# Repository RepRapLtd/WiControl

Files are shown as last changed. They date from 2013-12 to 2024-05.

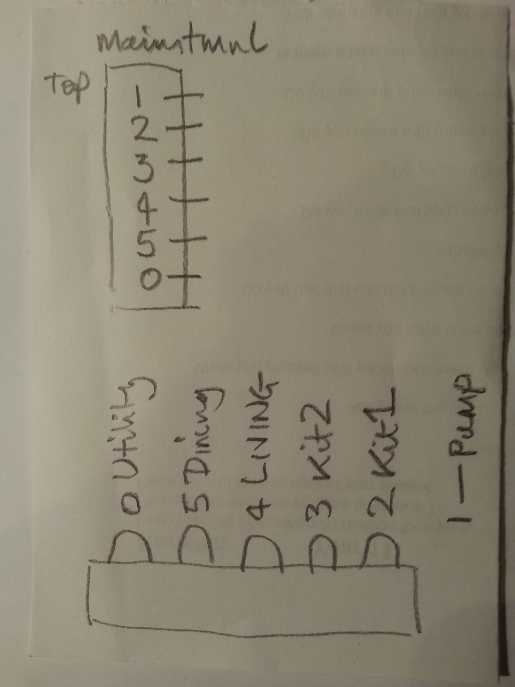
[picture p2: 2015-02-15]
PanStamp/Electronics/uf-connections.jpg

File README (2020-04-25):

Wireless Home/Building Control System
=====================================

Adrian Bowyer
RepRap Ltd
https://reprapltd.com

Licence: GPL

This is a system for controlling devices in buildings (primarily, but not exclusively, heating; it will also do lighting and other things) with a web interface.  It is fully open-source and free.  The licence is the GPL.

There are two versions:

  1. Raspberry Pi + PanStamp in the directory PanStamp. This has been working for a few years, and is now frozen and will not be developed further.

  2. WiFi based on the ESP-8266 in the directory ESP-8266.  This is in development.

Both start with a php script that serves web pages where you can edit, for example, temperature profiles for individual rooms.  That data is saved in files on the server.

The ESP-8266s (or Pi) then get that data and decide(s) what to turn on and off.

More documentation needs to be written...

More importantly, security is minimal and needs to be properly implemented.

See also (for homemade solenoid valves): https://www.thingiverse.com/thing:3496770

WiControl - ESP-8266
====================

This version does everything that the PanStamp version did, but more simply and robustly (the robustness has nothing to do with the hardware change; the PanStamps are fine; it has to do with a simplification of the protocols and hardware).

This version of the system will also support Google Home and Amazon Echo/Alexa.

Some more instructions here would be a good idea...

WiControl - Raspberry Pi + PanStamp
===================================

This allows temperature profiles to be set for each individual room for all times of the day and every day of the week.

It can be controlled using a web browser from anywhere.

It uses Panstamps (http://www.panstamp.com/) for the individual rooms and a Raspberry Pi (https://www.raspberrypi.org/) as the main building controller.

This repository contains all the software and all the hardware designs.

One thing it lacks is full documentation, as I created it for my own use and I know how it works.  Sorry.

Installation:
-------------

On the Pi:

This assumes you have an out-of-the-box Raspberry Pi SD card with no extra software installed.

First set your local timezone:

$ sudo dpkg-reconfigure tzdata

You may want to change the default name of the Pi ("raspberrypi") to something more appropriate 
like "heatingcontrol".  To do that:

$ sudo nano /etc/hostname

That file contains a single name - the name of the Pi.  Change it to what you want, save the file, then reboot.

Change you password:

$ passwd

And enable ssh:

$ sudo raspi-config

Next install Apache and PHP:

$ sudo apt-get update
$ sudo apt-get install apache2 -y
$ sudo apt-get install php5 libapache2-mod-php5 -y

At this point it is a good idea to check that the webserver is now running.  In the URL address bar of a web browser on a PC or phone type

  myname.home/

where myname is the Pi's name that you created above (some networks need myname.local instead).  If you don't get anything type 

$ ifconfig

on the Pi.  This will tell you the Pi's IP address (something like 192.168.1.163).  Type that IP address into the web browser's URL bar.  You should see the default Apache/Debian server homepage.

Next install ftp:

$ sudo apt-get install ftp

And the ftp demon:

$ sudo apt-get install pure-ftpd

Create an ftp user (see https://www.raspberrypi.org/documentation/remote-access/ftp.md) called "upload" with access to the html directory:

$ sudo groupadd ftpgroup
$ sudo useradd ftpuser -g ftpgroup -s /sbin/nologin -d /dev/null
$ pushd /var/www/html/
$ sudo chown -R ftpuser:ftpgroup .
$ sudo pure-pw useradd upload -u ftpuser -g ftpgroup -d /var/www/html -m
[** You will be asked to create a password for the user upload at this point**]
$ sudo pure-pw mkdb
$ sudo ln -s /etc/pure-ftpd/conf/PureDB /etc/pure-ftpd/auth/60puredb
$ sudo service pure-ftpd restart
$ popd

You next need to install the heating software:

$ git clone https://github.com/RepRapLtd/WiControl.git
$ cd WiControl/PanStamp

Copy the control file:

$ cp run-heat-control.sample run-heat-control

and edit the file run-heat-control and replace the "zone-1"s with the name of the zone you want.

Copy the sending file:

$ cp sendtemps.sample sendtemps

and edit the sendtemps file to include the ftp password you set above and to change zone-1 to the name of your zone.

Backup the webserver's index file, and copy all the heating web files there and set permissions:

$ sudo mv /var/www/html/index.html /var/www/html/index.html.old
$ cd Web
$ sudo cp -r * /var/www/html
$ sudo chown -R ftpuser:ftpgroup /var/www/html
$ sudo chmod 666 /var/www/html/*.dat
$ sudo chmod 777 /var/www/html/zone-1-Profiles

Finally

$ sudo crontab -e

and add a line at the end like this:

* * * * * /home/pi/WiControl/run-heat-control

That will cause the shell script run-heat-control to be run once a minute.

On the PanStamps:

You can just about run the Arduino IDE on the Raspberry Pi, but it's probably better to
use a big serious computer to do this bit.  Install the Arduino IDE on your computer if
you haven't already got it:

https://www.arduino.cc/en/Main/Software

And clone the repository https://github.com/RepRapLtd/WiControl.git as you did on the Pi.

Load the arduino program in the folder Panstamp-control into the IDE.

At the head of the file Control.h set up your heating zones and device names and numbers.  Load 
this program into each device (e.g. boiler, radiator) on your heating system.

Running
-------

When it runs it creates a status file called Status.

$ cat Status

will tell you what your system last did.  If you

$ touch Log

then each time run-heat-control runs it will append the status
report to the end of itself, which keeps a history and is therefore
useful for debugging.

When you have finished debugging don't forget to

$ rm Log

otherwise it will eventually fill up the SD/disc...

Adrian Bowyer

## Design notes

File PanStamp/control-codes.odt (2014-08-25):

Panstamp Heating etc control control codes

C0

Sleep or reset? Not yet implemented.

C1 Pn Hv [Ds]

Set output n to v. n = 0 is the MOSFET. Outputs 1 to 5 are on the 7 pin header, which goes:

+12v

Gnd

1 (Arduino D8)

2 (Arduino D9) - Not available in LED control mode

3 (Arduino A3 = D17)

4 (Arduino A1 = D15)

5 (Arduino A2 = D16)

The action happens after d seconds (default 0s).

C2

Return my temperature. When wireless requested this gives an integer in 0.1 degrees Celsius. From the serial interface it just gives degrees Celsius.

C3 An Ssome command

Send "some command" to device n

C4

Print/send firmware version number and my address.

C5 Pn Hv

Low level set Arduino pin n to value v. NB this also sets pin n to output mode.

C6 r0.7 g0.2 b0.1

Sets the LEDs to the rgb values specified in the range [0, 1].

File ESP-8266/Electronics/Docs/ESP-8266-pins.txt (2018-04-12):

esp8266_peri.h:#define GPC0   ESP8266_REG(0x328) //GPIO_PIN0 D3 (mini)
esp8266_peri.h:#define GPC1   ESP8266_REG(0x32C) //GPIO_PIN1 TX (mini)
esp8266_peri.h:#define GPC2   ESP8266_REG(0x330) //GPIO_PIN2 D4 (mini)
esp8266_peri.h:#define GPC3   ESP8266_REG(0x334) //GPIO_PIN3 RX (mini)
esp8266_peri.h:#define GPC4   ESP8266_REG(0x338) //GPIO_PIN4 D2 (mini)
esp8266_peri.h:#define GPC5   ESP8266_REG(0x33C) //GPIO_PIN5 D1 (mini)
esp8266_peri.h:#define GPC6   ESP8266_REG(0x340) //GPIO_PIN6 -
esp8266_peri.h:#define GPC7   ESP8266_REG(0x344) //GPIO_PIN7 
esp8266_peri.h:#define GPC8   ESP8266_REG(0x348) //GPIO_PIN8
esp8266_peri.h:#define GPC9   ESP8266_REG(0x34C) //GPIO_PIN9
esp8266_peri.h:#define GPC10  ESP8266_REG(0x350) //GPIO_PIN10
esp8266_peri.h:#define GPC11  ESP8266_REG(0x354) //GPIO_PIN11
esp8266_peri.h:#define GPC12  ESP8266_REG(0x358) //GPIO_PIN12 D6 (mini)
esp8266_peri.h:#define GPC13  ESP8266_REG(0x35C) //GPIO_PIN13 D7 (mini)
esp8266_peri.h:#define GPC14  ESP8266_REG(0x360) //GPIO_PIN14 D5 (mini)
esp8266_peri.h:#define GPC15  ESP8266_REG(0x364) //GPIO_PIN15 D8 (mini)
                                                 //GPIO_PIN16 D0 (mini)
LED_BUILTIN

d1-mini:

#define LED_BUILTIN 2

static const uint8_t D0   = 16;
static const uint8_t D1   = 5;
static const uint8_t D2   = 4;
static const uint8_t D3   = 0;
static const uint8_t D4   = 2;
static const uint8_t D5   = 14;
static const uint8_t D6   = 12;
static const uint8_t D7   = 13;
static const uint8_t D8   = 15;
static const uint8_t RX   = 3;
static const uint8_t TX   = 1;

d1:

#define LED_BUILTIN 2 //new ESP-12E GPIO2

static const uint8_t D0   = 3;
static const uint8_t D1   = 1;
static const uint8_t D2   = 16;
static const uint8_t D3   = 5;
static const uint8_t D4   = 4;
static const uint8_t D5   = 14;
static const uint8_t D6   = 12;
static const uint8_t D7   = 13;
static const uint8_t D8   = 0;
static const uint8_t D9   = 2;
static const uint8_t D10  = 15;
static const uint8_t D11  = 13;
static const uint8_t D12  = 12;
static const uint8_t D13  = 14;
static const uint8_t D14  = 4;
static const uint8_t D15  = 5;

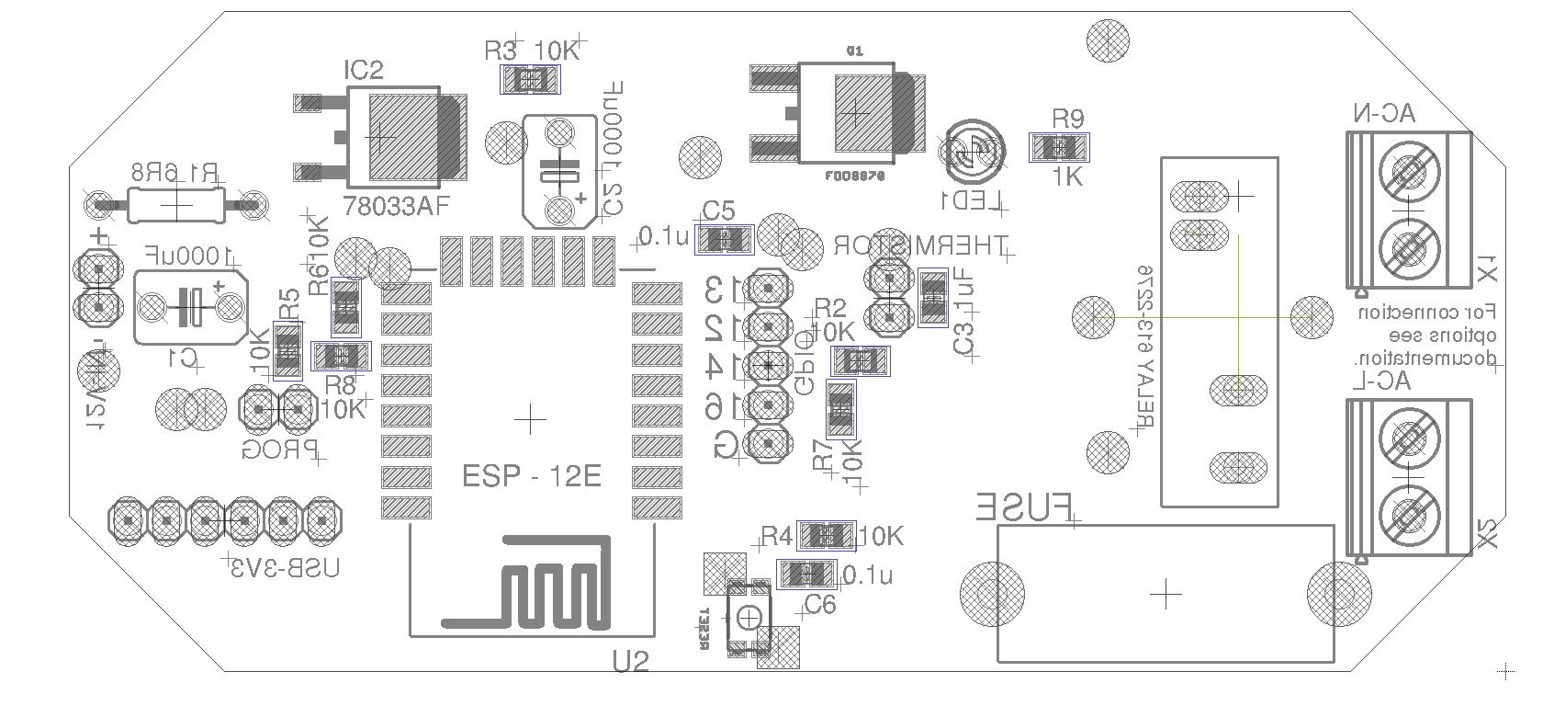
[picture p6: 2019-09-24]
ESP-8266/Electronics/PCB-under.png

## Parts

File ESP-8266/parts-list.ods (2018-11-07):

 | Part | Value | Totals | Supplier | Supplier part # | Our Part No | Item Description | Qty in stock | Qty to Order | Ordered
23 | ← Number of units
Electronics
 | 2 pin head |  | 3 |  |  |  | PCB pin header – 2 pin | 300 | -231
 | 5 pin head |  | 1 |  |  |  | PCB pin header – 5 pin | 70 | -47
 | 6 pin head |  | 1 |  |  |  | PCB pin header – 6 pin | 70 | -47
 | C2 | 1000uF | 2 | RS | 711-0980 |  | Electrolytic capacitor | 11 | 35 | 50
 | C3 | 1uF | 1 | RS | 698-3409 |  | 805 SMT capacitor | 16 | 7 | 10
 | C6 | 0.1u | 2 | Farnell | 2852354 |  | 805 SMT capacitor | 28 | 18
 | IC2 | 78033AF | 1 | RS | 751-5192 |  | 3.3V SMT regulator | 46 | -23
 | LED1 (red) | 3mm red LED | 1 | RS | 127-8385 |  | red LED | 45 | -22
 | Flying LED (grn) | 3mm green LED | 1 | RS | 247-1375 |  | green LED | 70 | -47
 | Q1 | FDD8870 | 1 | RS | 809-0950 |  | SMT power MOSFET | 6 | 17 | 20
 | R9 | 1K | 1 | RS | 901-3682 |  | 805 SMT resistor | 91 | -68
 | (R10) | 220R | 1 | RS | 683-2783 |  | 0.125W axial-lead resistor | 17 | 6 | 25
 | RESET | membrane button | 1 | Amazon/Ebay |  |  | push switch | 25 | -2
 | U$1 | FUSE | 0 | RS | 176-9047 |  | PCB fuse holder | 3 | -3
 | U$2 | relay | 0 | RS | 613-2276 |  | PCB 12v/240v relay | 2 | -2
 | U2 | ESP12E | 1 | Amazon/Ebay |  |  | SMT wireless module | 0 | 23
 | X2 | AC-L | 1 | RS | 144-4330 |  | 2-pin PCB screw terminal 5mm pitch | 14 | 9 | 10
 | Power supply |  | 1 | EBay |  |  | 12V 1A or 2A power supply | 0 | 23
 | thermistor |  | 1 | RS | 538-0806 |  | Thermistor | 6 | 17 | 20
 | 2-pin shell |  | 2 |  |  |  | Crimp socket shell | 11 | 35
 | 4-pin shell |  | 1 |  |  |  | Crimp socket shell | 74 | -51
 | PCB |  | 1 | PCB Train |  |  | PCB | 32 | -9
Mechanics
 | Woodscrews |  | 10 | Amazon/EBay |  |  | 10mm x 3mm | 180 | 50
Printed
(Bump-STLs) | base.stl |  | 1 |  |  |  | printed | 0 | 23
 | cable-clamp.stl |  | 1 |  |  |  | printed | 0 | 23
 | led-cover.stl |  | 1 |  |  |  | printed | 0 | 23
 | lid.stl |  | 1 |  |  |  | printed | 0 | 23
 | separator.stl |  | 1 |  |  |  | printed | 0 | 23
 | walls.stl |  | 1 |  |  |  | printed | 0 | 23
Total devices
 | Workshop: | 7
 | Sally & Ben: | 9
 | Adrian & Christine: | 13 | + 1 spare

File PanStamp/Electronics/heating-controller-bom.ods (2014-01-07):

 |  |  |  |  |  | To make: | 10
Part | Value | Device | Package | Description | No off | stock | required | Buy | RS
B1 |  | B-DIL | B-DIL | RECTIFIER | 1 | 34 | 10 | 0 | 629-5995
C1 | 1000uF | CPOL-EUE3.5-10 | E3,5-10 | POLARIZED CAPACITOR, European symbol | 1 | 0 | 10 | 10 | 711-1148 |  | #
C2 | 100uF | CPOL-EUE3.5-10 | E3,5-10 | POLARIZED CAPACITOR, European symbol | 1 | 0 | 10 | 10 | 684-1942 |  | #
C3 | 4.7uF | CPOL-EUE3.5-10 | E3,5-10 | POLARIZED CAPACITOR, European symbol | 1 | 0 | 10 | 10 | 116-852 |  | #
C4, C5 | 100nF | C-EU050-024X044 | C050-024X044 | CAPACITOR, European symbol | 2 | 35 | 20 | 0 | 721-5240 |  | #
IC1 | TS2950-3v3 | LP2950ACZ-3.0 | TO92 | Source: http://cache.national.com/ds/LP/LP2950.pdf | 1 | 8 | 10 | 2 | 762-0430 |  | #
JP1 |  | PINHD-1X6 | 1X06 | PIN HEADER | 1 | 0 | 10 | 10
JP2 |  | PINHD-1X2 | 1X02 | PIN HEADER | 1 | 0 | 10 | 10
JP3 |  | PINHD-1X7 | 1X07 | PIN HEADER | 1 | 0 | 10 | 10
LED1 |  | LED3MM | LED3MM | LED | 1 | 0 | 10 | 10 | 619-4886 |  | #
LED2 |  | LED3MM | LED3MM | LED | 1 | 0 | 10 | 10 | 247-1606 |  | #
LED3 |  | LED3MM | LED3MM | LED | 1 | 0 | 10 | 10 | 466-3576 |  | #
Q1 | IRLB8721PBF | PMOSFET_NTO220BV | TO220BV | Power MOSFET N-Channel | 1 | 3 | 10 | 7 | 725-9322 |  | #
R1, R3 | 220R | R-EU_0207/7 | 0207/7 | RESISTOR, European symbol | 2 | 0 | 20 | 20 | 707-7612 |  | #
R2, R4 | 1K | R-EU_0207/7 | 0207/7 | RESISTOR, European symbol | 1 | 0 | 10 | 10 | 707-7666 |  | #
R5 | 538-0806 | THERMISTOR-2,5 | RS-2,5 | THERMISTOR | 1 | 3 | 10 | 7 | 538-0806 |  | #
U$1 | PANSTAMPPANSTAMP | PANSTAMPPANSTAMP | DIL24-6 | Panstamp wireless module | 1 | 6 | 10 | 4
X1 |  | W237-6 | W237-6 | WAGO SCREW CLAMP | 1 | 0 | 10 | 10 | 361-7702 |  | #
PCB |  |  |  |  | 1 | 49 | 10 | 0
Socket strip |  | Soc-12 |  |  | 2 | 0 | 20 | 20 | 517-974-01-16 | <-Mouser
Mains sw. | SCR | S202T01 |  |  | 1 | 5 | 10 | 5 | 667-5225
jumper |  |  |  |  | 1 | 0 | 10 | 10 | 674-2397 |  | #

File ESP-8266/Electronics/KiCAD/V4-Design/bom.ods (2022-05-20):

C1 | 1000u | Capacitor_THT:CP_Radial_D10.0mm_P5.00mm
C2 | 1u | Capacitor_SMD:C_0805_2012Metric
C3 | 1000u | Capacitor_THT:CP_Radial_D10.0mm_P5.00mm
C4 | 0.1u | Capacitor_SMD:C_0805_2012Metric
C5 | 0.1u | Capacitor_SMD:C_0805_2012Metric
D1 | LED | LED_THT:LED_D3.0mm
D2 | LED | LED_THT:LED_D3.0mm
H1 | MountingHole | MountingHole:MountingHole_2.5mm
H2 | MountingHole | MountingHole:MountingHole_2.5mm
H3 | MountingHole | MountingHole:MountingHole_2.5mm
H4 | MountingHole | MountingHole:MountingHole_2.5mm
J1 | PWR | Connector_PinHeader_2.54mm:PinHeader_1x02_P2.54mm_Vertical
J2 | thermistor | Connector_PinHeader_2.54mm:PinHeader_1x02_P2.54mm_Vertical
J3 | Aux1 | Connector_PinHeader_2.54mm:PinHeader_1x05_P2.54mm_Vertical
J4 | Aux2 | Connector_PinHeader_2.54mm:PinHeader_1x07_P2.54mm_Vertical
J5 | USB-3V3 | Connector_PinHeader_2.54mm:PinHeader_1x06_P2.54mm_Vertical
J6 | PROG | Connector_PinHeader_2.54mm:PinHeader_1x02_P2.54mm_Vertical
J7 | OUT | Connector_PinHeader_2.54mm:PinHeader_1x03_P2.54mm_Vertical
J8 | mains | TerminalBlock:TerminalBlock_bornier-2_P5.08mm
J9 | led-select | Connector_PinHeader_2.54mm:PinHeader_1x02_P2.54mm_Vertical
JP1 | SolderJumper_2_Bridged | Jumper:SolderJumper-2_P1.3mm_Bridged_RoundedPad1.0x1.5mm
K1 | CPC1966Y | reprapltd-kicad:CPC1966Y
Q1 | FDD8870 | Package_TO_SOT_SMD:TO-252-2
R1 | 6R8 | Resistor_THT:R_Axial_DIN0414_L11.9mm_D4.5mm_P15.24mm_Horizontal
R10 | 180R | Resistor_SMD:R_0805_2012Metric
R11 | 1K | Resistor_SMD:R_0805_2012Metric
R2 | 10K | Resistor_SMD:R_0805_2012Metric
R3 | 10K | Resistor_SMD:R_0805_2012Metric
R4 | 10K | Resistor_SMD:R_0805_2012Metric
R5 | 180R | Resistor_SMD:R_0805_2012Metric
R6 | 10K | Resistor_SMD:R_0805_2012Metric
R7 | 10K | Resistor_SMD:R_0805_2012Metric
R8 | 10K | Resistor_SMD:R_0805_2012Metric
R9 | 10K | Resistor_SMD:R_0805_2012Metric
Reference |  | Value
SW1 | reset | Button_Switch_SMD:SW_SPST_TL3342
U1 | ESP-12E | esp-8266:ESP-12E
U2 | 78033 | Package_TO_SOT_SMD:TO-252-2

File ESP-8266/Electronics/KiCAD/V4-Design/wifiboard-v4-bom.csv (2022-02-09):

Reference | Value | Footprint | Datasheet | Arrow Part Number | Arrow Price/Stock | Description | Height | Manufacturer_Name | Manufacturer_Part_Number | Mouser Part Number | Mouser Price/Stock
J5 | USB-3V3 | Connector_PinHeader_2.54mm:PinHeader_1x06_P2.54mm_Vertical | ~
J3 | Aux1 | Connector_PinHeader_2.54mm:PinHeader_1x05_P2.54mm_Vertical | ~
J4 | Aux2 | Connector_PinHeader_2.54mm:PinHeader_1x07_P2.54mm_Vertical | ~
C4 | 0.1u | Capacitor_SMD:C_0805_2012Metric | ~
J2 | thermistor | Connector_PinHeader_2.54mm:PinHeader_1x02_P2.54mm_Vertical | ~
C2 | 1u | Capacitor_SMD:C_0805_2012Metric | ~
R2 | 10K | Resistor_SMD:R_0805_2012Metric | ~
R3 | 10K | Resistor_SMD:R_0805_2012Metric | ~
C5 | 0.1u | Capacitor_SMD:C_0805_2012Metric | ~
R4 | 10K | Resistor_SMD:R_0805_2012Metric | ~
SW1 | reset | Button_Switch_SMD:SW_SPST_TL3342 | ~
R1 | 6R8 | Resistor_THT:R_Axial_DIN0414_L11.9mm_D4.5mm_P15.24mm_Horizontal | ~
J1 | PWR | Connector_PinHeader_2.54mm:PinHeader_1x02_P2.54mm_Vertical | ~
C1 | 1000u | Capacitor_THT:CP_Radial_D10.0mm_P5.00mm | ~
C3 | 1000u | Capacitor_THT:CP_Radial_D10.0mm_P5.00mm | ~
J6 | PROG | Connector_PinHeader_2.54mm:PinHeader_1x02_P2.54mm_Vertical | ~
R8 | 10K | Resistor_SMD:R_0805_2012Metric | ~
R6 | 10K | Resistor_SMD:R_0805_2012Metric | ~
R7 | 10K | Resistor_SMD:R_0805_2012Metric | ~
R9 | 10K | Resistor_SMD:R_0805_2012Metric | ~
D1 | LED | LED_THT:LED_D3.0mm | ~
R5 | 180R | Resistor_SMD:R_0805_2012Metric | ~
U1 | ESP-12E | esp-8266:ESP-12E | http://l0l.org.uk/2014/12/esp8266-modules-hardware-guide-gotta-catch-em-all/
D2 | LED | LED_THT:LED_D3.0mm | ~
R10 | 180R | Resistor_SMD:R_0805_2012Metric | ~
J7 | OUT | Connector_PinHeader_2.54mm:PinHeader_1x03_P2.54mm_Vertical | ~
K1 | CPC1966Y | reprapltd-kicad:CPC1966Y | https://datasheet.datasheetarchive.com/originals/distributors/Datasheets_SAMA/4bd38bcd53ac06cbf93d43ee226943fd.pdf | CPC1966Y | https://www.arrow.com/en/products/cpc1966y/ixys | IXYS 3 A rms SPNO Solid State Relay, Zero Crossing, PCB Mount SCR, 240 V ac Maximum Load | 10 | LITTELFUSE | CPC1966Y | 849-CPC1966Y | https://www.mouser.co.uk/ProductDetail/IXYS-Integrated-Circuits/CPC1966Y?qs=8uBHJDVwVqxNfAOiNv29Iw%3D%3D
R11 | 1K | Resistor_SMD:R_0805_2012Metric | ~
J8 | mains | TerminalBlock:TerminalBlock_bornier-2_P5.08mm | ~
Q1 | FDD8870 | Package_TO_SOT_SMD:TO-252-2 | http://www.jaolen.com/images/pdf/QM6006D.pdf
H4 | MountingHole | MountingHole:MountingHole_2.5mm | ~
H3 | MountingHole | MountingHole:MountingHole_2.5mm | ~
H2 | MountingHole | MountingHole:MountingHole_2.5mm | ~
H1 | MountingHole | MountingHole:MountingHole_2.5mm | ~
J9 | led-select | Connector_PinHeader_2.54mm:PinHeader_1x02_P2.54mm_Vertical | ~
U2 | 78033 | Package_TO_SOT_SMD:TO-252-2 | http://www.st.com/content/ccc/resource/technical/document/datasheet/41/4f/b3/b0/12/d4/47/88/CD00000444.pdf/files/CD00000444.pdf/jcr:content/translations/en.CD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
JP1 | SolderJumper_2_Bridged | Jumper:SolderJumper-2_P1.3mm_Bridged_RoundedPad1.0x1.5mm | ~

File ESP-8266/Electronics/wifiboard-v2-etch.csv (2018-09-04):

Part | Value | Device | Package | Description | PROD_ID | VALUE
12V-IN |  | PINHD-1X2 | 1X02 | PIN HEADER
C1 | 1000uF | CPOL-EUB45181B | B45181B | POLARIZED CAPACITOR, European symbol
C2 | 1000uF | CPOL-EUB45181B | B45181B | POLARIZED CAPACITOR, European symbol
C3 | 1uF | C-EUC0805 | C0805 | CAPACITOR, European symbol
C5 | 0.1u | C-EUC0805 | C0805 | CAPACITOR, European symbol
C6 | 0.1u | C-EUC0805 | C0805 | CAPACITOR, European symbol
GPIO |  | PINHD-1X5 | 1X05 | PIN HEADER
IC2 | 78033AF | 7805DT | TO252 | Positive VOLTAGE REGULATOR
LED1 |  | LED3MM | LED3MM | LED
PROG |  | PINHD-1X2 | 1X02 | PIN HEADER
Q1 | FDD8870 | MOSFET-NCH-FDD8780 | DPAK | N-channel MOSFETs | TRANS-09984 | 35A/25V/8.5mΩ
R1 | 6R8 | R-EU_0207/10 | 0207/10 | RESISTOR, European symbol
R2 | 10K | R-EU_M0805 | M0805 | RESISTOR, European symbol
R3 | 10K | R-EU_M0805 | M0805 | RESISTOR, European symbol
R4 | 10K | R-EU_R0805 | R0805 | RESISTOR, European symbol
R5 | 10K | R-EU_R0805 | R0805 | RESISTOR, European symbol
R6 | 10K | R-EU_R0805 | R0805 | RESISTOR, European symbol
R7 | 10K | R-EU_R0805 | R0805 | RESISTOR, European symbol
R8 | 10K | R-EU_R0805 | R0805 | RESISTOR, European symbol
R9 | 1K | R-EU_R0805 | R0805 | RESISTOR, European symbol
RESET |  | MOMENTARY-SWITCH-SPST-SMD-4.6X2.8MM | TACTILE_SWITCH_SMD_4.6X2.8MM | Momentary Switch (Pushbutton) - SPST | SWCH-13065
THERMISTOR |  | PINHD-1X2 | 1X02 | PIN HEADER
U$1 | FUSE | FUSE | FUSE
U$2 | OMRON-G6DS | OMRON-G6DS | OMRON-G6DS-1A-H
U2 |  | ESP12ESMD | ESP12E-SMD | ESP12E Module
USB-3V3 |  | PINHD-1X6 | 1X06 | PIN HEADER
X1 | AC-N | MKDSN1,5/2-5,08 | MKDSN1,5/2-5,08 | MKDSN 1,5/ 2-5,08 Printklemme
X2 | AC-L | MKDSN1,5/2-5,08 | MKDSN1,5/2-5,08 | MKDSN 1,5/ 2-5,08 Printklemme

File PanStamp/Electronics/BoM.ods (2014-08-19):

 |  | no reqd |  | needed | RS
item | no off | 18 | stock
panstamp | 1 | 18 | 25 | -7
PCB | 1 | 18 | 39 | -21
6 way screw con | 1 | 18 | 5 | 13 | 361-7702 | x
Thermistor | 1 | 18 | 8 | 10 | 538-0806 | x
green LED | 1 | 18 | 20 | -2 | 247-1606
red LED | 1 | 18 | 34 | -16 | 619-4886
orange LED | 1 | 18 | 10 | 8 | 466-3576 | x
220R | 2 | 36 | 0 | 36 | 707-7612 | x
1K | 2 | 36 | 0 | 36 | 707-7666 | x
1000uF | 1 | 18 | 16 | 2 | 711-1148 | x
100uF | 1 | 18 | 1 | 17 | 684-1942 | x
4.7uF | 1 | 18 | 1 | 17 | 116-852 | x
100nF | 2 | 36 | 31 | 5 | 653-0119 | x
MOSFET | 1 | 18 | 4 | 14 | 725-9322 | x
Jumper | 1 | 18 | 39 | -21 | 674-2397
6x pin header | 1 | 18 | 0 | 18
7x pin header | 1 | 18 | 0 | 18
2x pin header | 2 | 36 | 0 | 36
3v3 reg | 1 | 18 | 9 | 9 | 762-0430 | x
 |  |  |  | 0
Case + lid | 1 | 18 | 8 | 10
12v PSU | 1 | 18 | 6 | 12 |  | x
screws | 4 | 72 | 50 | 22
opto SCR |  | 8 | 3 | 5 | 667-5225 | x

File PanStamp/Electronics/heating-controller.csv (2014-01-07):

Part | Value | Device | Package | Description | MF | MPN | OC_FARNELL | OC_NEWARK
B1 |  | B-DIL | B-DIL | RECTIFIER
C1 | 1000uF | CPOL-EUE3.5-10 | E3,5-10 | POLARIZED CAPACITOR, European symbol
C2 | 100uF | CPOL-EUE3.5-10 | E3,5-10 | POLARIZED CAPACITOR, European symbol
C3 | 4.7uF | CPOL-EUE3.5-10 | E3,5-10 | POLARIZED CAPACITOR, European symbol
C4 | 100nF | C-EU050-024X044 | C050-024X044 | CAPACITOR, European symbol
C5 | 100nF | C-EU050-024X044 | C050-024X044 | CAPACITOR, European symbol
H1 | MOUNT-PAD-ROUND2.8 | MOUNT-PAD-ROUND2.8 | 2,8-PAD | MOUNTING PAD, round
H2 | MOUNT-PAD-ROUND2.8 | MOUNT-PAD-ROUND2.8 | 2,8-PAD | MOUNTING PAD, round
H3 | MOUNT-PAD-ROUND2.8 | MOUNT-PAD-ROUND2.8 | 2,8-PAD | MOUNTING PAD, round
H4 | MOUNT-PAD-ROUND2.8 | MOUNT-PAD-ROUND2.8 | 2,8-PAD | MOUNTING PAD, round
IC1 | TS2950-3v3 | LP2950ACZ-3.0 | TO92 | Source: http://cache.national.com/ds/LP/LP2950.pdf
JP1 |  | PINHD-1X6 | 1X06 | PIN HEADER
JP2 |  | PINHD-1X2 | 1X02 | PIN HEADER
JP3 |  | PINHD-1X7 | 1X07 | PIN HEADER
LED1 |  | LED3MM | LED3MM | LED
LED2 |  | LED3MM | LED3MM | LED
LED3 |  | LED3MM | LED3MM | LED
Q1 | IRLB8721PBF | PMOSFET_NTO220BV | TO220BV | Power MOSFET N-Channel
R1 | 220R | R-EU_0207/7 | 0207/7 | RESISTOR, European symbol
R2 | 1K | R-EU_0207/7 | 0207/7 | RESISTOR, European symbol
R3 | 220R | R-EU_0207/7 | 0207/7 | RESISTOR, European symbol
R4 | 1K | R-EU_0207/7 | 0207/7 | RESISTOR, European symbol
R5 | 538-0806 | THERMISTOR-2,5 | RS-2,5 | THERMISTOR
U$1 | PANSTAMPPANSTAMP | PANSTAMPPANSTAMP | DIL24-6 | Panstamp wireless module
X1 |  | W237-6 | W237-6 | WAGO SCREW CLAMP |  |  | unknown | unknown

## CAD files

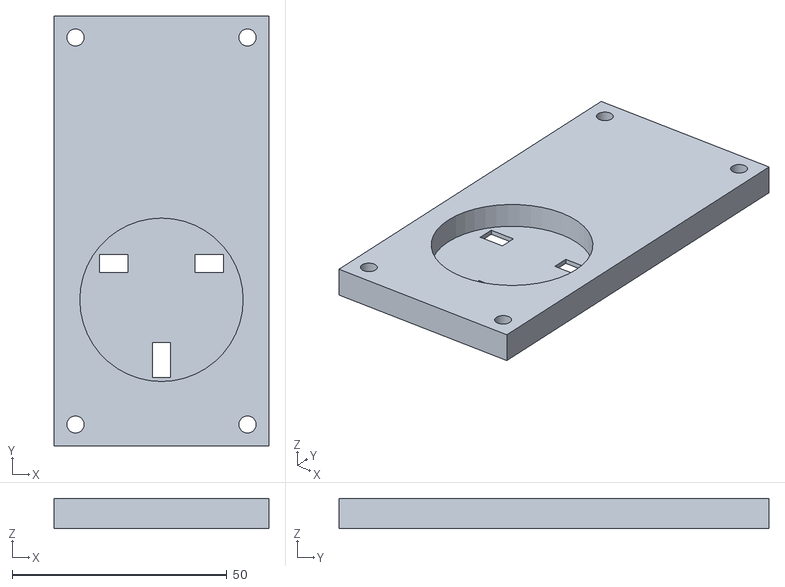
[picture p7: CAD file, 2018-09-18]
ESP-8266/Mechanics/Disc-STLs/base.stl
50.0 x 100.0 x 7.00

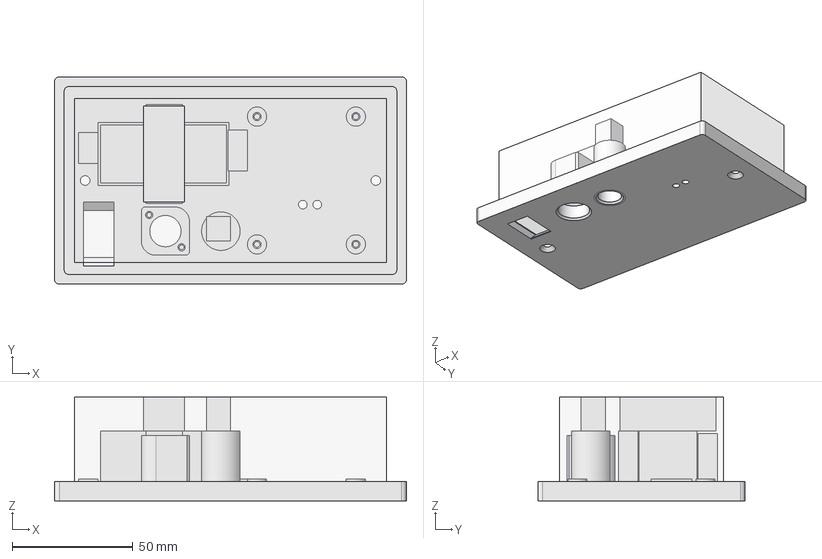
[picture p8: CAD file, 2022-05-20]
ESP-8266/Mechanics/double-patress-holder-no-chamfer.FCStd
146.0 x 86.0 x 43.0 mm
pcb
patress-cavity
PSU
terminal-block
jack-soc
front-plate

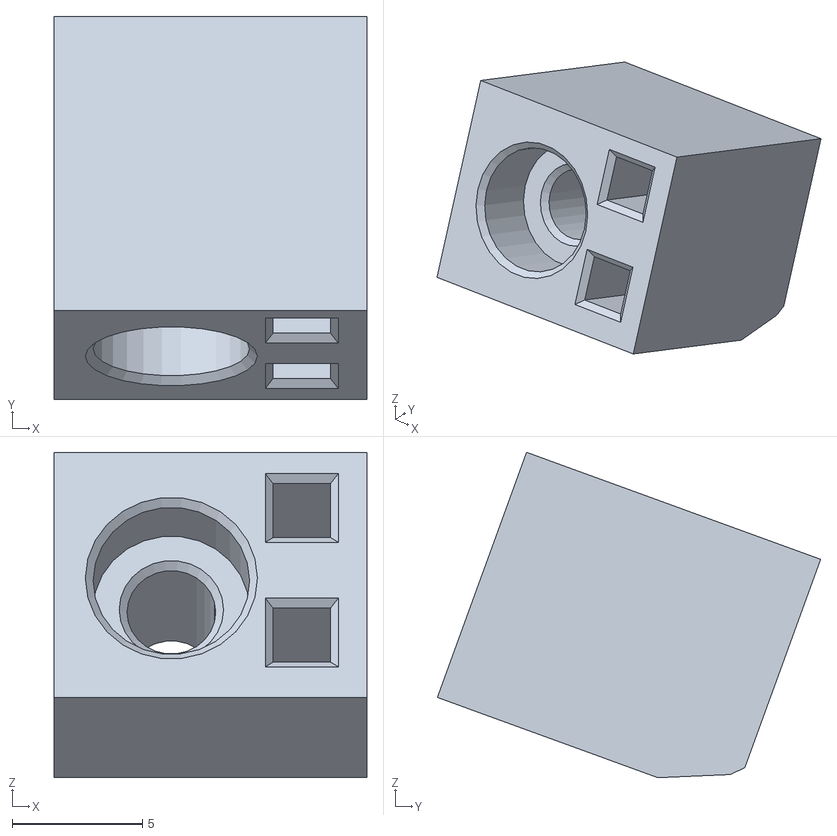
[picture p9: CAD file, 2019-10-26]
ESP-8266/Mechanics/STLs/Bump-STLs/plug.stl
12.0 x 14.7 x 12.5

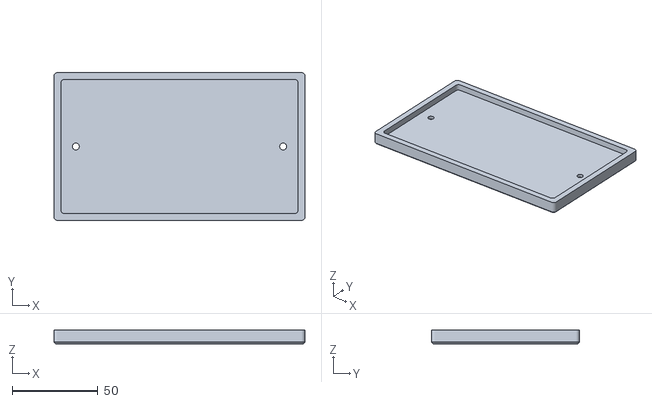
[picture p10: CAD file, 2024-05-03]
ESP-8266/Mechanics/STLs/double-patress-plate-blank.stl
146.0 x 86.0 x 8.00

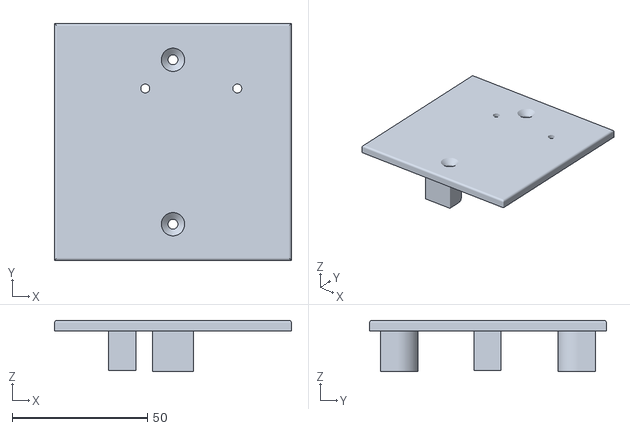
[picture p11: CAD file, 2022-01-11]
ESP-8266/Mechanics/STLs/Wifi Patress Box/Wifi Patress-Lid.stl
87.5 x 87.5 x 19.0

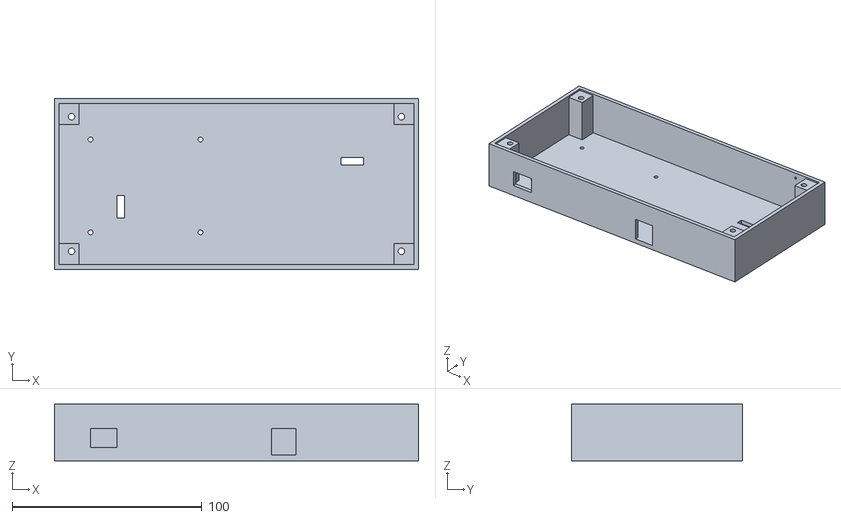
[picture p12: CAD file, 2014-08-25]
PanStamp/Mechanical/r-pi-case.stl
192.0 x 90.0 x 30.0

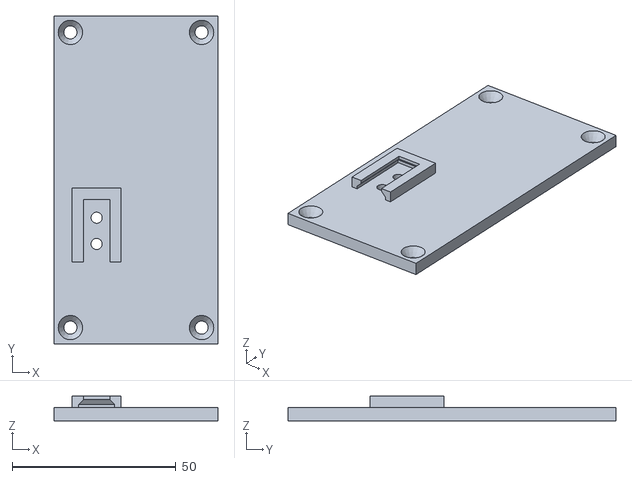
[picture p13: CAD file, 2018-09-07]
ESP-8266/Mechanics/Disc-STLs/lid.stl
50.0 x 100.0 x 7.50

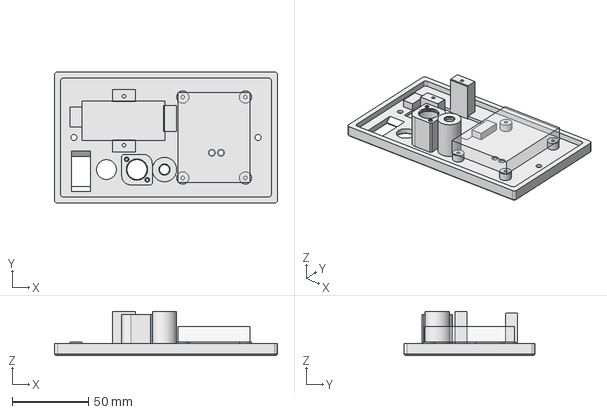
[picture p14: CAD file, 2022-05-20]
ESP-8266/Mechanics/double-patress-holder-v1.1.FCStd
146.0 x 86.0 x 29.0 mm
pcb
front-plate

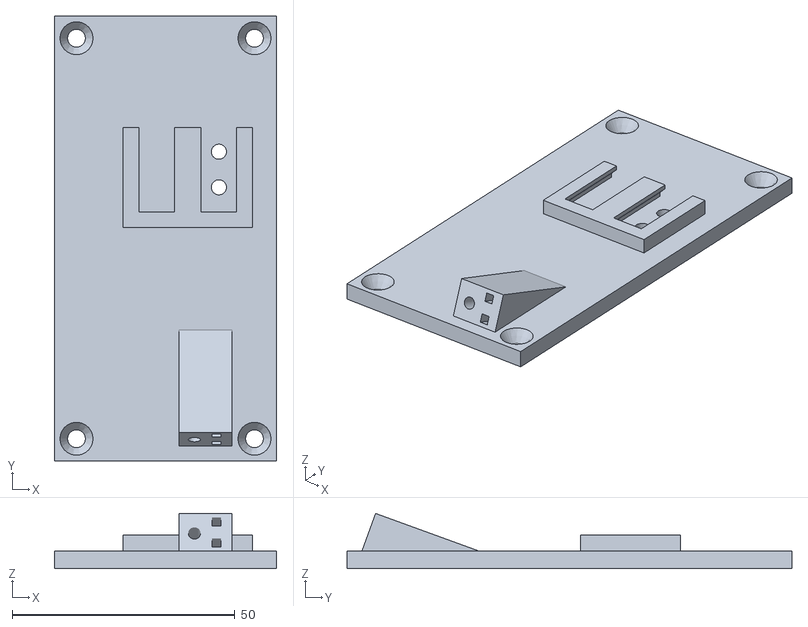
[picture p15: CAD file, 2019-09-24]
ESP-8266/Mechanics/STLs/Bump-STLs/lid-with-connector.stl
50.0 x 100.0 x 12.4

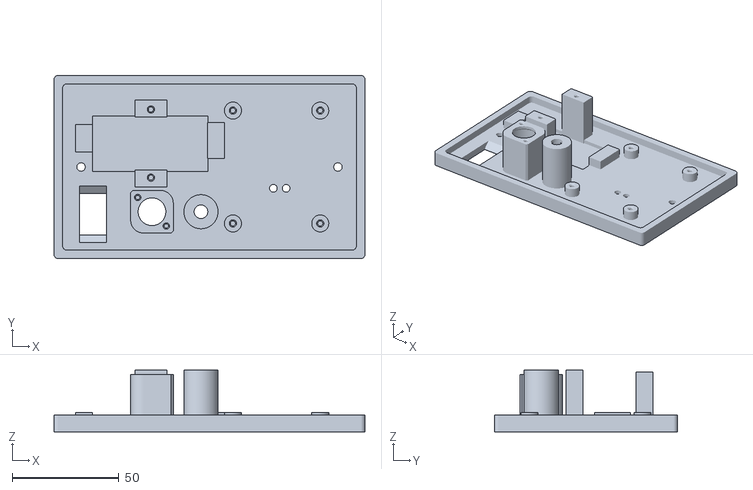
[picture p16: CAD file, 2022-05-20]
ESP-8266/Mechanics/STLs/double-patress-holder-front-plate-no-chamfer.stl
146.0 x 86.0 x 29.0

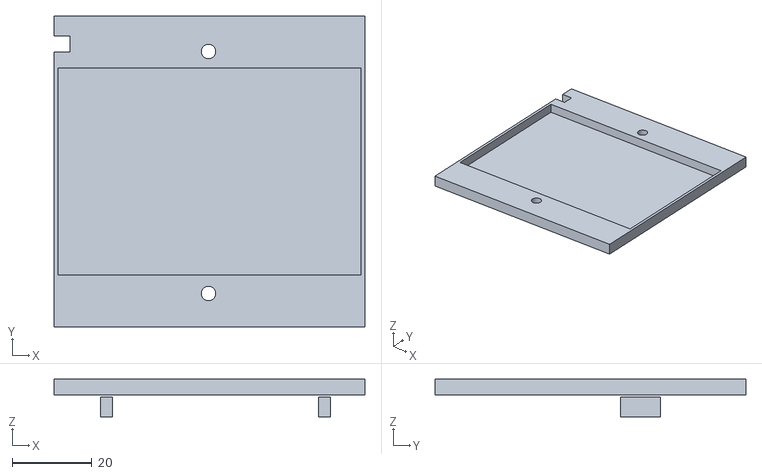
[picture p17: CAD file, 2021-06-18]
ESP-8266/Mechanics/STLs/Wifi Patress Box/Divider002.stl
78.0 x 78.0 x 9.50

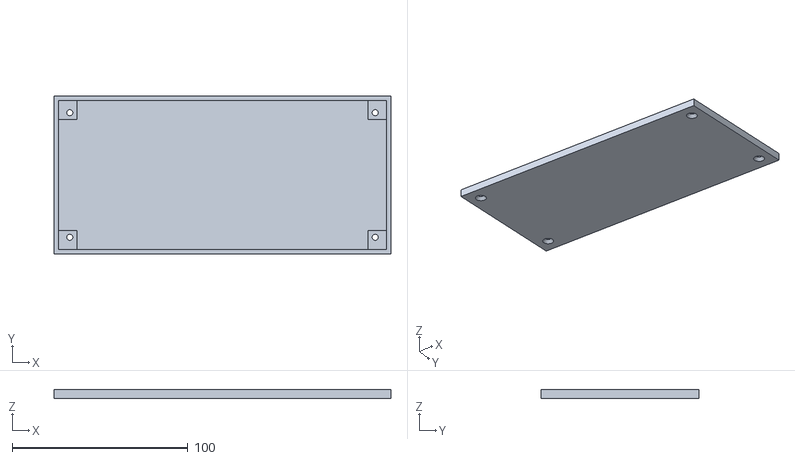
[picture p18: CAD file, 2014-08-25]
PanStamp/Mechanical/r-pi-lid.stl
192.0 x 90.0 x 5.00

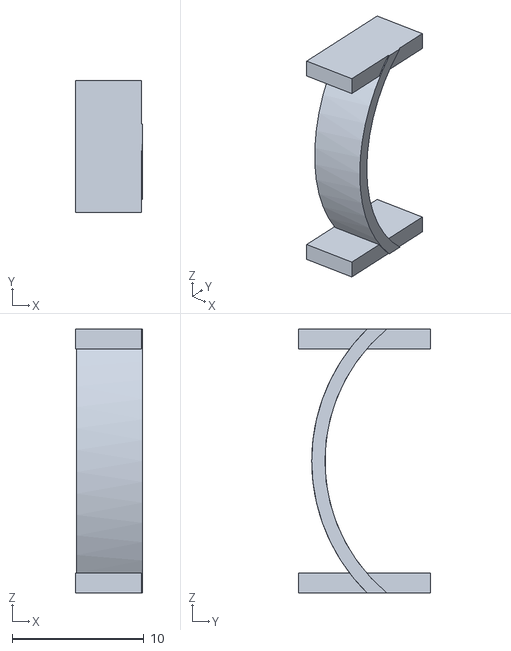
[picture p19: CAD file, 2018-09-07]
ESP-8266/Mechanics/Disc-STLs/spring-3-off.stl
5.10 x 10.0 x 20.0

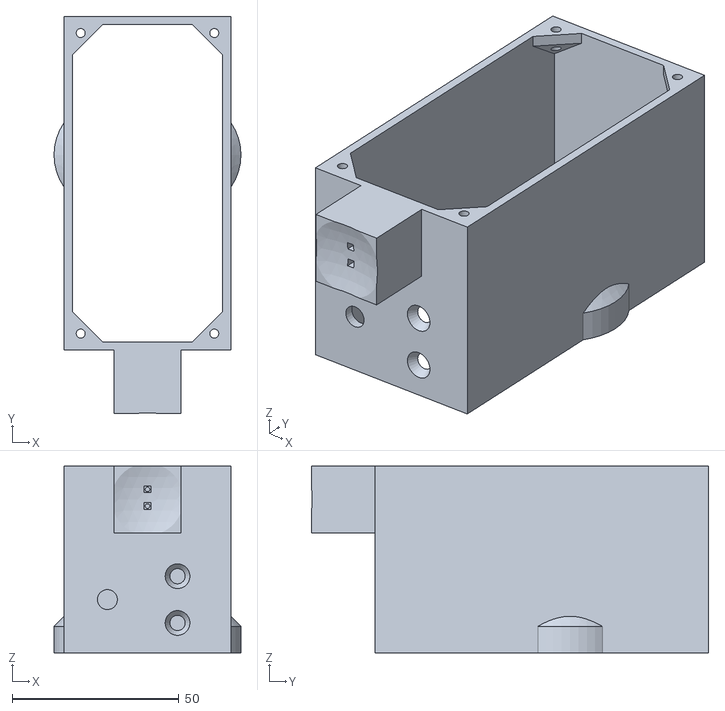
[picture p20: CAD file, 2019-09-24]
ESP-8266/Mechanics/STLs/Bump-STLs/walls.stl
56.0 x 119.0 x 56.0

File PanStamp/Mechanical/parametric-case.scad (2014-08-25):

Case(box=[192,90,30], wall=2.5, screws=3.5/2, countersink=false);


module Holes(box, wall)
{
   union()
	{

// Each pattern is looking at each face; RH XY coordinates; bottom left corner = (0,0)
// except the base, which is looking from on-top/inside.

// Base

	translate([0,0,-box.z/2]) 
	translate([-box.x/2,-box.y/2,0])
	{
		translate([15+4, 15.5+4, 0])
			cylinder(r=1.3, h=4*wall, center=true, $fn=20);
		translate([15+4, 15.5+4+49, 0])
			cylinder(r=1.3, h=4*wall, center=true, $fn=20);
		translate([15+4+58, 15.5+4, 0])
			cylinder(r=1.3, h=4*wall, center=true, $fn=20);
		translate([15+4+58, 15.5+4+49, 0])
			cylinder(r=1.3, h=4*wall, center=true, $fn=20);

		translate([35, 33, 0])
			cube([4,12,4*wall], center=true);
		translate([box.x-35, box.y-33, 0])
			cube([12,4,4*wall], center=true);	
	}

// Low X face

	translate([-box.x/2,0,0])rotate([0,-90,0])rotate([0,0,-90])translate([-box.y/2, -box.z/2, 0])
	{
		//translate([15, 15, 0])
		//	cylinder(r=2, h=4*wall, center=true);

	}

// High X face

	translate([box.x/2,0,0])rotate([0,90,0])rotate([0,0,90])translate([-box.y/2, -box.z/2, 0])
	{
		//translate([15, 19, 0])
		//	cube([4,15,4*wall], center=true);

	}

// Low Y face

	translate([0,-box.y/2,0])rotate([90,0,0])translate([-box.x/2, -box.z/2, 0])
	{
		translate([15+4+7, 12, 0])
			cube([14,10,4*wall], center=true);
		translate([15+4+102, 10, 0])
			cube([13,14,4*wall], center=true);
	}



// High Y face

	translate([0,box.y/2,0])rotate([-90,0,0])rotate([0,0,180])translate([-box.x/2, -box.z/2, 0])
	{
		translate([box.x-(15+4+152), 24+wall, 0])
			cylinder(r=0.7, h=4*wall, center=true, $fn=20);		

	}

	}

}

module Corners(box, rad, solid, countersink)
{
	xcen = box.x-18;
	ycen = box.y-19;

	for(x=[-1,1])for(y=[-1,1])
		translate([x*xcen/2,y*ycen/2,0])
		{
			if(solid)
			{
				translate([2*x,2*y,0])
					cube([12,12,box.z-2], center=true);
			} else
			{
				cylinder(r=rad, h=box.z*3, center=true, $fn=20);
				if(countersink)
				{
					translate([0,0,-box.z/2+0.8])
						cylinder(r1=2.3*rad, r2=rad, h=2.5, center=true, $fn=20);
				}
			}
		}
}

module Case(box=[60,40,30], wall=2.5, screws=1.75, countersink=false)
{
	difference()
	{
		union()
		{
			difference()
			{
				cube(box, center=true);
				translate([0,0,wall])
					cube([box.x-2*wall, box.y-2*wall, box.z], center=true);
			}
			Corners(box, screws, true, countersink);
		}
		Holes(box, wall);
		Corners(box, screws, false, countersink);
	}

}

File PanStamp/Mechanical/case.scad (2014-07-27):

//cubex=120; //71;
//cubey=130; //73;
cubex=71;
cubey=73;
xcen = cubex-18;
ycen = cubey-19;
dia = 3.5;
thick=8;
lid=true;
ribbonNotch=true;
//offx=cubex/2-71/2;
//offy=cubey/2-73/2;
offx = 0;
offy=0;

case();



module slot()
{
	translate([dia,0,0])
		cylinder(r=dia/2,h=60, center=true,$fn=20);
	translate([-dia,0,0])
		cylinder(r=dia/2,h=60, center=true,$fn=20);
	cube([2*dia,dia,60],center=true);	
}

module corner(box, rr)
{
	translate([offx, offy, 0])
	{
	for(x=[-1,1])for(y=[-1,1])
		translate([x*xcen/2,y*ycen/2,0])
		{
			if(box)
			{
				translate([2*x,2*y,-1])
					cube([12,12,thick], center=true);
			} else
			{
				cylinder(r=rr, h=40, center=true, $fn=20);
				if(lid)
				{
				translate([0,0,-thick/4-0.8])
				cylinder(r1=2.3*rr, r2=rr, h=2.5, center=true, $fn=20);
				}
			}
		}
}
}

module case()
{

difference()
{
	translate([offx, offy, 0])
		cube([cubex,cubey,thick], center=true);


	if(lid)
	{
		translate([-xcen/2,ycen/2,0])
		{
			translate([9,-2,0])
				cylinder(r=1.7, h=40, center=true, $fn=20);
			translate([9+6.5,-2,0])
			cylinder(r=1.7, h=40, center=true, $fn=20);
			translate([9+6.5+6.3,-2,0])
			cylinder(r=1.7, h=40, center=true, $fn=20);
		}
		translate([20-xcen/2,-ycen/2-3,0])
		{
			translate([-2,0,0])
					cylinder(r=1, h=40, center=true, $fn=20);
			translate([2,0,0])
			cylinder(r=1, h=40, center=true, $fn=20);
		}
		corner(box=false, rr=dia/2);
		if(ribbonNotch)
		{
			translate([-xcen/2-5,12,7.5])
				cube([10,17,10], center=true);
		}
	} else
	{
		translate([xcen/2,-ycen/2,12.5-1-4])
		{
			translate([-30,-2,0])
				rotate([90,0,0])
					cylinder(r=2.5, h=40, center=true, $fn=20);

			translate([-30+10+10,-2,0])
				rotate([90,0,0])
					cylinder(r=2.5, h=40, center=true, $fn=20);
		}

		translate([-xcen/2,ycen/2,12.5-14])
					translate([30-10,-2,0])
				rotate([90,0,0])
					cylinder(r=1, h=40, center=true, $fn=20);

		translate([xcen/4,-ycen/4,0])
			slot();
		translate([-xcen/4,ycen/4,0])
			rotate([0,0,90])
				slot();
		corner(box=false, rr=0.8*dia/2);
	}


translate([offx, offy, 0])
	difference()
	{
		translate([0,0,3])
		cube([cubex-6,cubey-6,thick], center=true, r=dia/2);
		corner(box=true, rr=dia/2);
	}

}

}

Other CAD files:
ESP-8266/Mechanics/STLs/double-patress-holder-front-plate.stl
ESP-8266/Mechanics/STLs/Wifi Patress Box/Wifi Patress-Cut014.stl
PanStamp/Mechanical/long-lid.stl
ESP-8266/Mechanics/Disc-STLs/walls.stl
PanStamp/Mechanical/scr-case.scad
ESP-8266/Legacy/Disc-STLs/cable-clamp.stl
ESP-8266/Legacy/Disc-STLs/led-cover.stl
ESP-8266/Legacy/Disc-STLs/separator.stl
ESP-8266/Legacy/Disc-STLs/walls.stl
ESP-8266/Mechanics/Disc-STLs/cable-clamp.stl
ESP-8266/Mechanics/Disc-STLs/led-cover.stl
ESP-8266/Mechanics/Disc-STLs/separator.stl
ESP-8266/Mechanics/STLs/Bump-STLs/base.stl
ESP-8266/Mechanics/STLs/Bump-STLs/led-cover.stl
ESP-8266/Mechanics/STLs/Bump-STLs/separator.stl
ESP-8266/Mechanics/STLs/Wifi Patress Box/Wifi Patress-Chamfer006.stl
ESP-8266/Mechanics/STLs/Wifi Patress Box/Wifi Patress-Divider001.stl
ESP-8266/Mechanics/STLs/Wifi Patress Box/Wifi Patress-Divider003.stl
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

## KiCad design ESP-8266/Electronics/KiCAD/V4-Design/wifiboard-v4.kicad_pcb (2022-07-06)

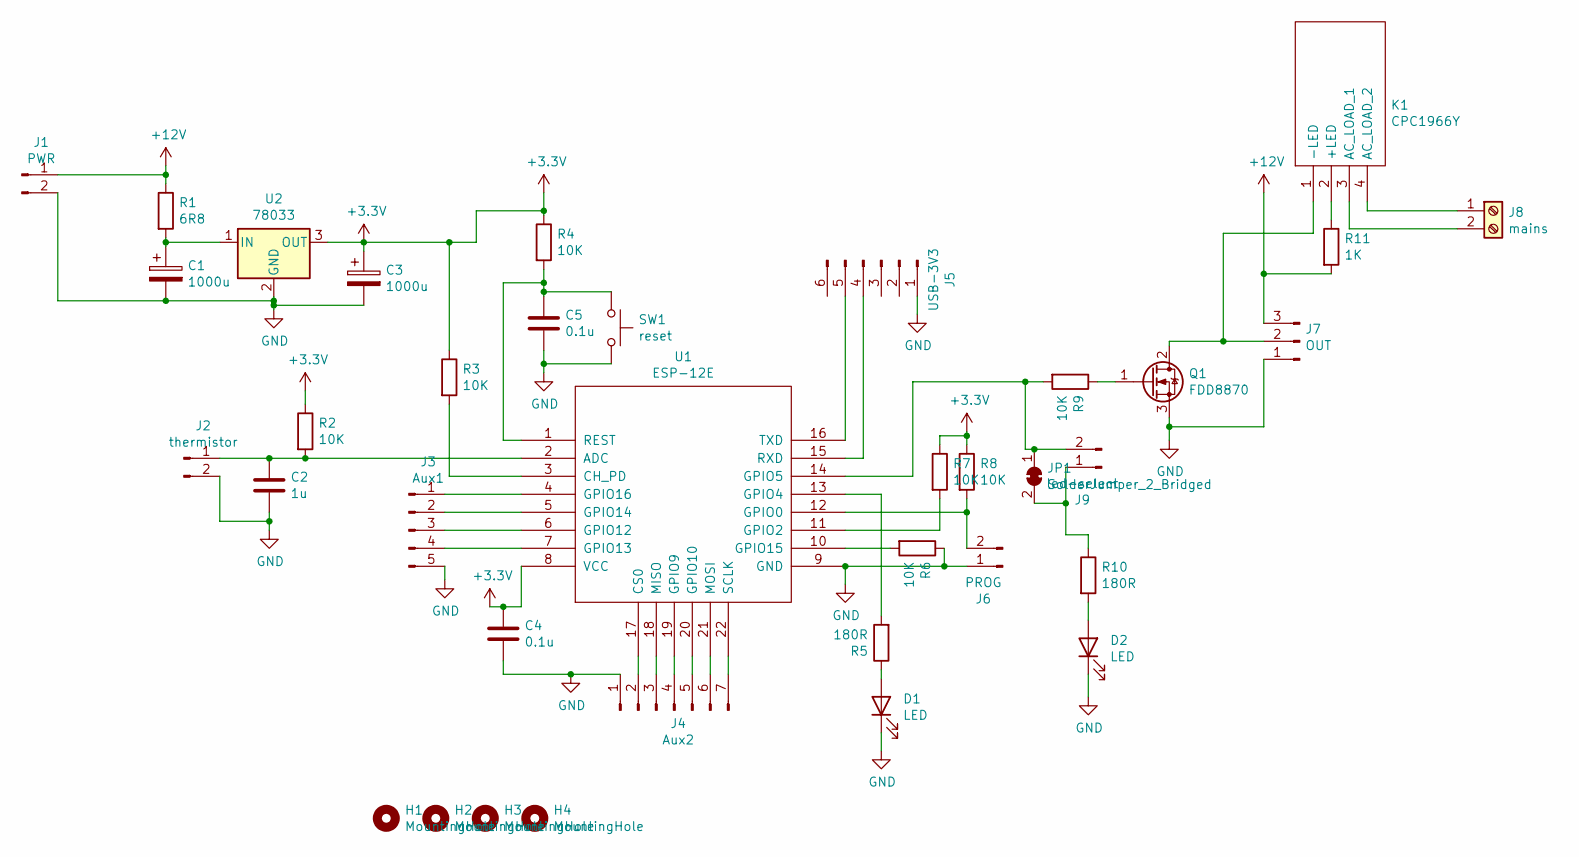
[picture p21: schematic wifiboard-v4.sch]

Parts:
C1, C3: 1000u; CP_Radial_D10.0mm_P5.00mm
C2: 1u; C_0805_2012Metric
C4, C5: 0.1u; C_0805_2012Metric
D1, D2: LED; LED_D3.0mm
H1, H2, H3, H4: MountingHole; MountingHole_2.5mm
J1: PWR; PinHeader_1x02_P2.54mm_Vertical
J2: thermistor; PinHeader_1x02_P2.54mm_Vertical
J3: Aux1; PinHeader_1x05_P2.54mm_Vertical
J4: Aux2; PinHeader_1x07_P2.54mm_Vertical
J5: USB-3V3; PinHeader_1x06_P2.54mm_Vertical
J6: PROG; PinHeader_1x02_P2.54mm_Vertical
J7: OUT; PinHeader_1x03_P2.54mm_Vertical
J8: mains; TerminalBlock_bornier-2_P5.08mm
J9: led-select; PinHeader_1x02_P2.54mm_Vertical
JP1: SolderJumper_2_Bridged; SolderJumper-2_P1.3mm_Bridged_RoundedPad1.0x1.5mm
K1: CPC1966Y; Manufacturer_Part_Number CPC1966Y; Mouser Part Number 849-CPC1966Y
Q1: FDD8870; TO-252-2
R1: 6R8; R_Axial_DIN0414_L11.9mm_D4.5mm_P15.24mm_Horizontal
R2, R3, R4, R6, R7, R8, R9: 10K; R_0805_2012Metric
R5, R10: 180R; R_0805_2012Metric
R11: 1K; R_0805_2012Metric
SW1: reset; SW_SPST_TL3342
U1: ESP-12E
U2: 78033; TO-252-2

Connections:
+3V3: C3.1, C4.1, R2.1, R3.1, R4.1, R7.1, R8.1, U1.8 (VCC), U2.3 (OUT)
+12V: J1.1, J7.3, R1.1, R11.2
GND: C1.2, C2.2, C3.2, C4.2, C5.2, D1.1 (K), D2.1 (K), J1.2, J2.2, J3.5, J4.1, J5.1, J6.1, J7.1, Q1.3 (S), R6.1, SW1.2, U1.9 (GND), U2.2 (GND)
unnamed: C1.1, R1.2, U2.1 (IN)
unnamed: C2.1, J2.1, R2.2, U1.2 (ADC)
unnamed: C5.1, R4.2, SW1.1, U1.1 (REST)
unnamed: D1.2 (A), R5.1
unnamed: D2.2 (A), R10.2
unnamed: J3.1, U1.4 (GPIO16)
unnamed: J3.2, U1.5 (GPIO14)
unnamed: J3.3, U1.6 (GPIO12)
unnamed: J3.4, U1.7 (GPIO13)
unnamed: J4.2, U1.17 (CS0)
unnamed: J4.3, U1.18 (MISO)
unnamed: J4.4, U1.19 (GPIO9)
unnamed: J4.5, U1.20 (GPIO10)
unnamed: J4.6, U1.21 (MOSI)
unnamed: J4.7, U1.22 (SCLK)
unnamed: J5.4, U1.15 (RXD)
unnamed: J5.5, U1.16 (TXD)
unnamed: J6.2, R8.2, U1.12 (GPIO0)
unnamed: J7.2, K1.1 (-LED), Q1.2 (D)
unnamed: J8.1, K1.4 (AC_LOAD_2)
unnamed: J8.2, K1.3 (AC_LOAD_1)
unnamed: J9.1, JP1.2 (B), R10.1
unnamed: J9.2, JP1.1 (A), R9.2, U1.14 (GPIO5)
unnamed: K1.2 (+LED), R11.1
unnamed: Q1.1 (G), R9.1
unnamed: R3.2, U1.3 (CH_PD)
unnamed: R5.2, U1.13 (GPIO4)
unnamed: R6.2, U1.10 (GPIO15)
unnamed: R7.2, U1.11 (GPIO2)

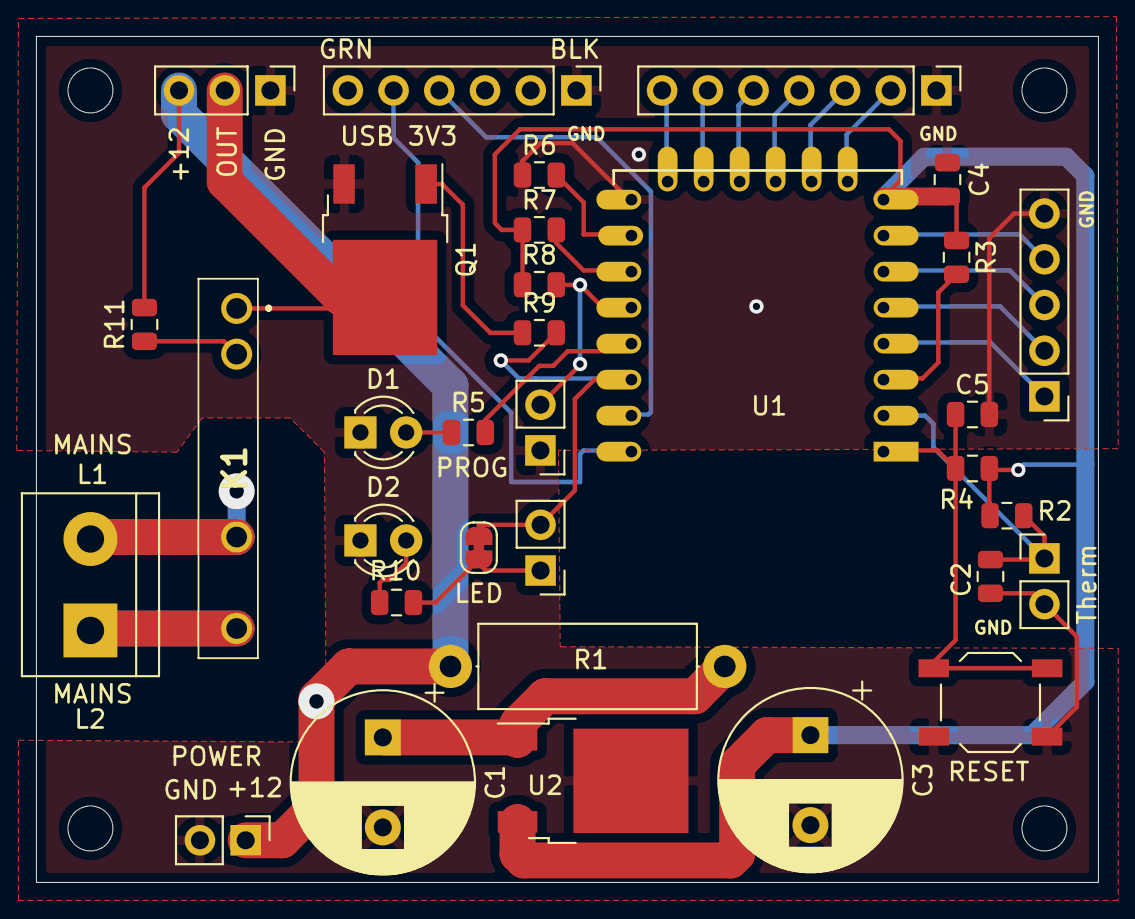
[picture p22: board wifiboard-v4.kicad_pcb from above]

Board: 2 copper layers, 59.0 x 47.0 mm, 37 parts (0 on the bottom side), 32 nets.

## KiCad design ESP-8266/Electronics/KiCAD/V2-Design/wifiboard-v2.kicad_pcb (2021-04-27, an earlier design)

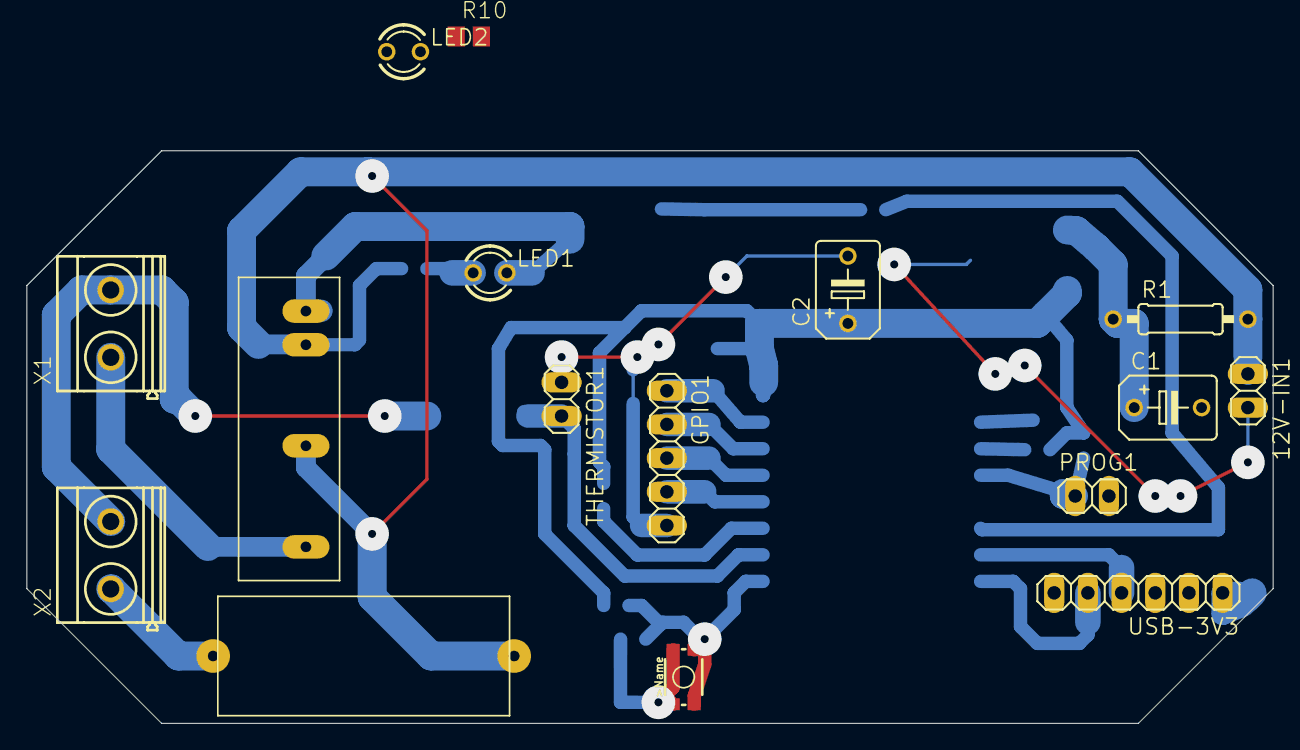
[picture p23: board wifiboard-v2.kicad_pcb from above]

Board: 2 copper layers, 94.0 x 43.2 mm, 30 parts (0 on the bottom side), 23 nets.

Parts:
12V-IN1: PINHD-1X2; 1X02
C1, C2: 1000uF; B45181B
C3: 1uF; C0805
C5, C6: 0.1u; C0805
FUSE1: FUSE
GPIO1: PINHD-1X5; 1X05
IC2: 78033AF; TO252
LED1, LED2: LED3MM
PROG1: PINHD-1X2; 1X02
Q1: FDD8870; DPAK
R1: 6R8; 0207_10
R2, R3: 10K; M0805
R4, R5, R6, R7, R8: 10K; R0805
R9: 1K; R0805
R10: 180R; R0805
RESET1: TACTILE_SWITCH_SMD_4.6X2.8MM
RLA1: OMRON-G6DN; OMRON-G6DN-1A
THERMISTOR1: PINHD-1X2; 1X02
U2: ESP12ESMD; ESP12E-SMD
USB-3V3: PINHD-1X6; 1X06
X1: AC-N; MKDSN1,5_2-5,08
X2: AC-L; MKDSN1,5_2-5,08

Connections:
+3V3: C2.+, C5.1, IC2.2, R2.1, R4.2, R5.2, R7.2, R8.2, U2.VCC
+12V: 12V-IN1.1, FUSE1.P$1, R1.2, R9.2, RLA1.P$2, RLA1.P$3
GND: 12V-IN1.2, C1.-, C2.-, C3.2, C5.2, C6.2, GPIO1.5, IC2.3, LED2.K, PROG1.2, Q1.3, R6.1, RESET1.3, RESET1.4, THERMISTOR1.1, U2.GND, USB-3V3.1, X1.2, X2.2
unnamed: C1.+, IC2.1, R1.1
unnamed: C3.1, R2.2, THERMISTOR1.2, U2.ADC
unnamed: C6.1, R4.1, RESET1.1, RESET1.2, U2.RESET
unnamed: FUSE1.P$2, X2.1
unnamed: GPIO1.1, U2.GPIO13
unnamed: GPIO1.2, U2.GPIO12
unnamed: GPIO1.3, U2.GPIO14
unnamed: GPIO1.4, U2.GPIO16
unnamed: LED1.A, R9.1
unnamed: LED1.K, Q1.4, RLA1.P$1
unnamed: LED2.A, R10.1
unnamed: PROG1.1, R5.1, U2.GPIO0
unnamed: Q1.1, R3.1
unnamed: R3.2, U2.GPIO5
unnamed: R6.2, U2.GPIO15
unnamed: R7.1, U2.CH_PD
unnamed: R8.1, U2.GPIO2
unnamed: RLA1.P$4, X1.1
unnamed: U2.RXD0, USB-3V3.4
unnamed: U2.TXD0, USB-3V3.5

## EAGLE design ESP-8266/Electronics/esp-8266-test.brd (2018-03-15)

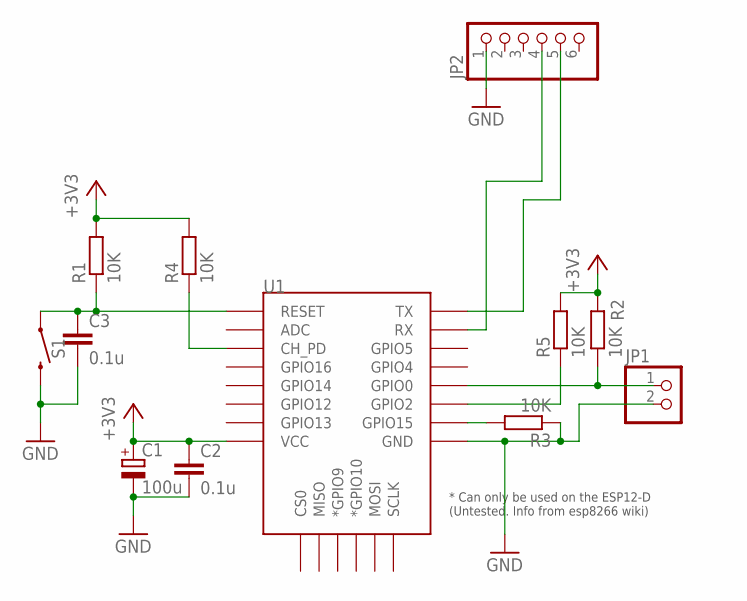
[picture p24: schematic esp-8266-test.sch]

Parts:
C1: 100u; 085CS_1AR
C2, C3: 0.1u; C0805
JP1: PINHD-1X2; 1X02
JP2: PINHD-1X6; 1X06
R1, R2, R3, R4, R5: 10K; R0805
S1: TACTILE_SWITCH_SMD_4.6X2.8MM
U1: ESP12ESMD; ESP12E-SMD

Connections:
+3V3: C1.+, C2.1, R1.2, R2.2, R4.2, R5.2, U1.VCC
GND: C1.-, C2.2, C3.2, JP1.2, JP2.1, R3.1, S1.3 (2), S1.4 (2), U1.GND
unnamed: C3.1, R1.1, S1.1, S1.2 (1), U1.RESET
unnamed: JP1.1, R2.1, U1.GPIO0
unnamed: JP2.4, U1.RXD0 (RX)
unnamed: R3.2, U1.GPIO15
unnamed: JP2.5, U1.TXD0 (TX)
unnamed: R4.1, U1.CH_PD
unnamed: R5.1, U1.GPIO2

Board: 2 copper layers, 12 parts (0 on the bottom side), 9 nets, no tracks yet.

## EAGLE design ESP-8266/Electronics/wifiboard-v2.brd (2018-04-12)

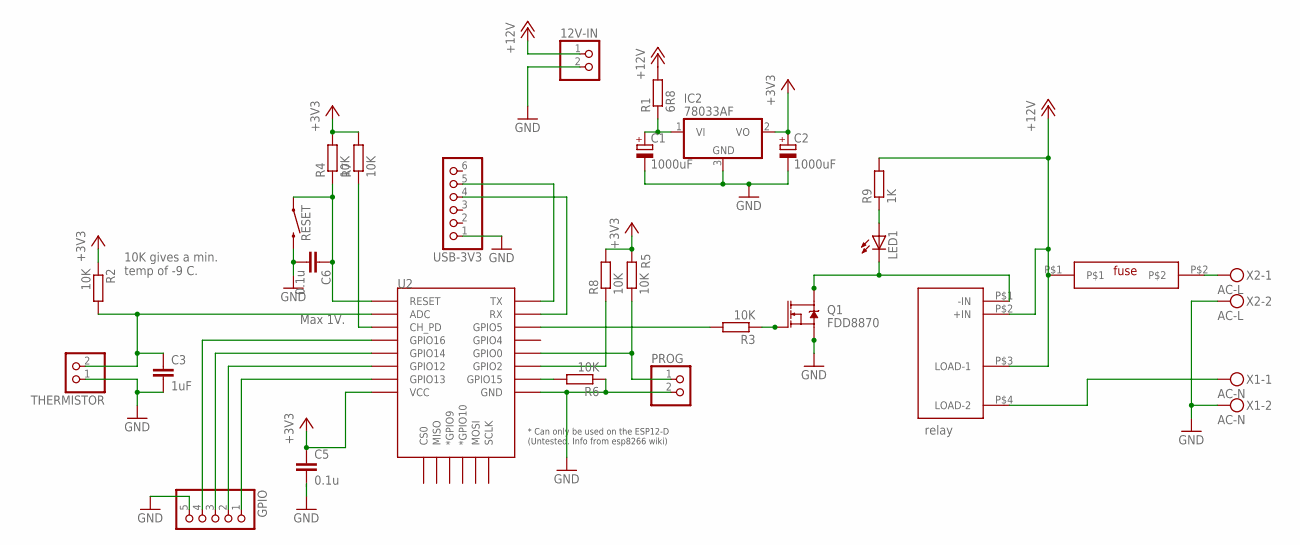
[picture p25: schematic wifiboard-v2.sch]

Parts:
12V-IN: PINHD-1X2; 1X02
C1, C2: 1000uF; B45181B
C3: 1uF; C0805
C5, C6: 0.1u; C0805
FUSE: FUSE
GPIO: PINHD-1X5; 1X05
IC2: 78033AF; TO252
LED1: LED3MM
PROG: PINHD-1X2; 1X02
Q1: FDD8870; DPAK
R1: 6R8; 0207/10
R2, R3: 10K; M0805
R4, R5, R6, R7, R8: 10K; R0805
R9: 1K; R0805
RELAY: OMRON-G6DS; OMRON-G6DS-1A-H
RESET: TACTILE_SWITCH_SMD_4.6X2.8MM
THERMISTOR: PINHD-1X2; 1X02
U2: ESP12ESMD; ESP12E-SMD
USB-3V3: PINHD-1X6; 1X06
X1: AC-N; MKDSN1,5/2-5,08
X2: AC-L; MKDSN1,5/2-5,08

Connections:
0: PROG.1, R5.1, U2.GPIO0
2: R8.1, U2.GPIO2
5: R3.2, U2.GPIO5
12: GPIO.2, U2.GPIO12
13: GPIO.1, U2.GPIO13
14: GPIO.3, U2.GPIO14
15: R6.2, U2.GPIO15
16: GPIO.4, U2.GPIO16
+3V3: C2.+, C5.1, IC2.2 (VO), R2.1, R4.2, R5.2, R7.2, R8.2, U2.VCC
+12V: 12V-IN.1, FUSE.P$1, R1.2, R9.2, RELAY.P$2 (+IN), RELAY.P$3 (LOAD-1)
A0: C3.1, R2.2, THERMISTOR.2, U2.ADC
CH_PD: R7.1, U2.CH_PD
GND: 12V-IN.2, C1.-, C2.-, C3.2, C5.2, C6.2, GPIO.5, IC2.3 (GND), PROG.2, Q1.3 (S), R6.1, RESET.3 (2), RESET.4 (2), THERMISTOR.1, U2.GND, USB-3V3.1, X1.2, X2.2
unnamed: C1.+, IC2.1 (VI), R1.1
unnamed: Q1.1 (G), R3.1
unnamed: LED1.K (C), Q1.4 (D), RELAY.P$1 (-IN)
unnamed: RELAY.P$4 (LOAD-2), X1.1
unnamed: FUSE.P$2, X2.1
unnamed: LED1.A, R9.1
RST: C6.1, R4.1, RESET.1, RESET.2 (1), U2.RESET
RX: U2.RXD0 (RX), USB-3V3.4
TX: U2.TXD0 (TX), USB-3V3.5

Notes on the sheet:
relay
10K gives a min. temp of -9 C.
Max 1V.

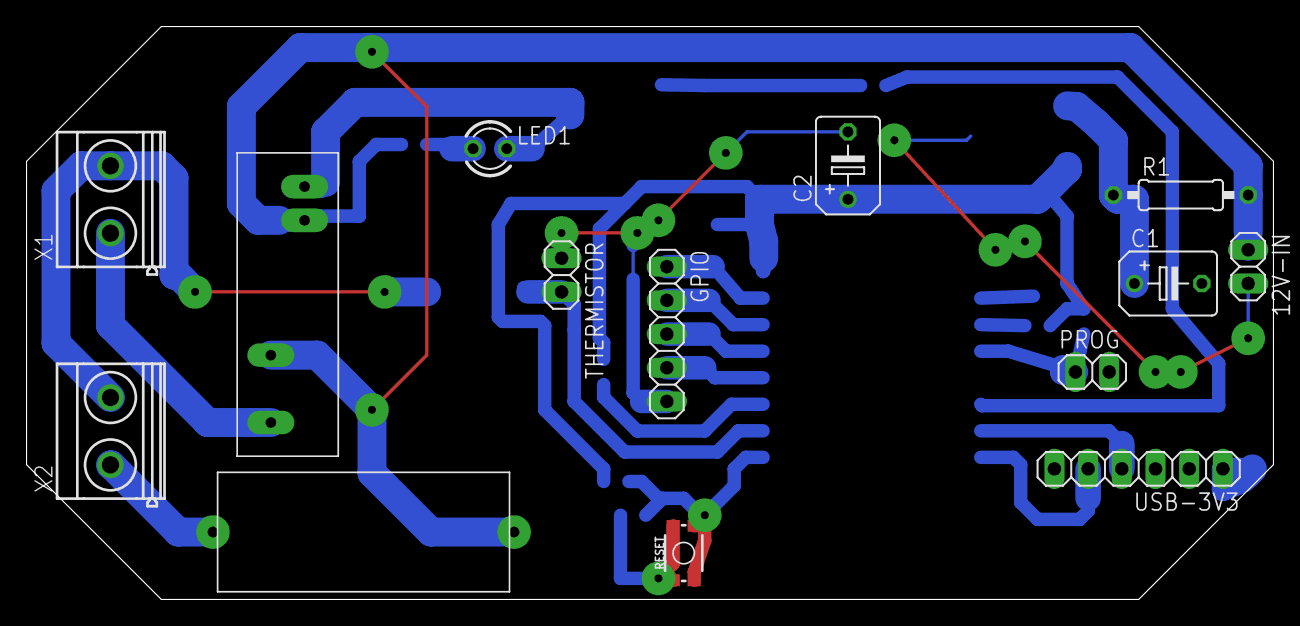
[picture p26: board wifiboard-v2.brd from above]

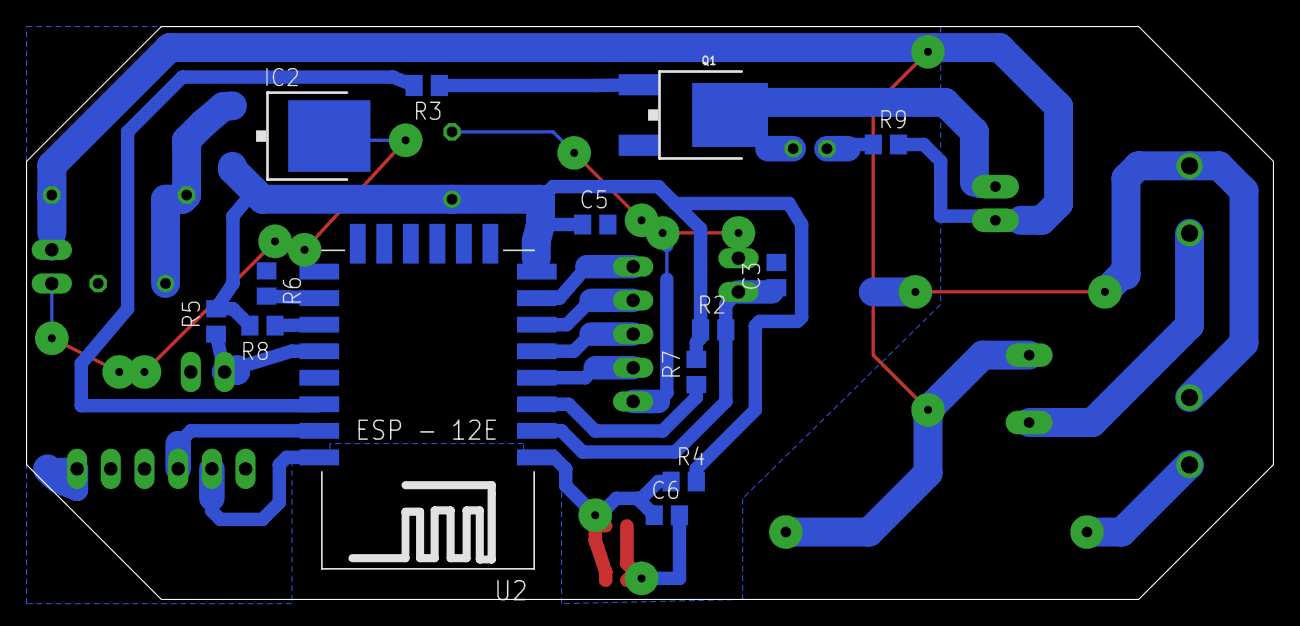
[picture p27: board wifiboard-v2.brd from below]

Board: 2 copper layers, 94.0 x 43.2 mm, 28 parts (14 on the bottom side), 22 nets.

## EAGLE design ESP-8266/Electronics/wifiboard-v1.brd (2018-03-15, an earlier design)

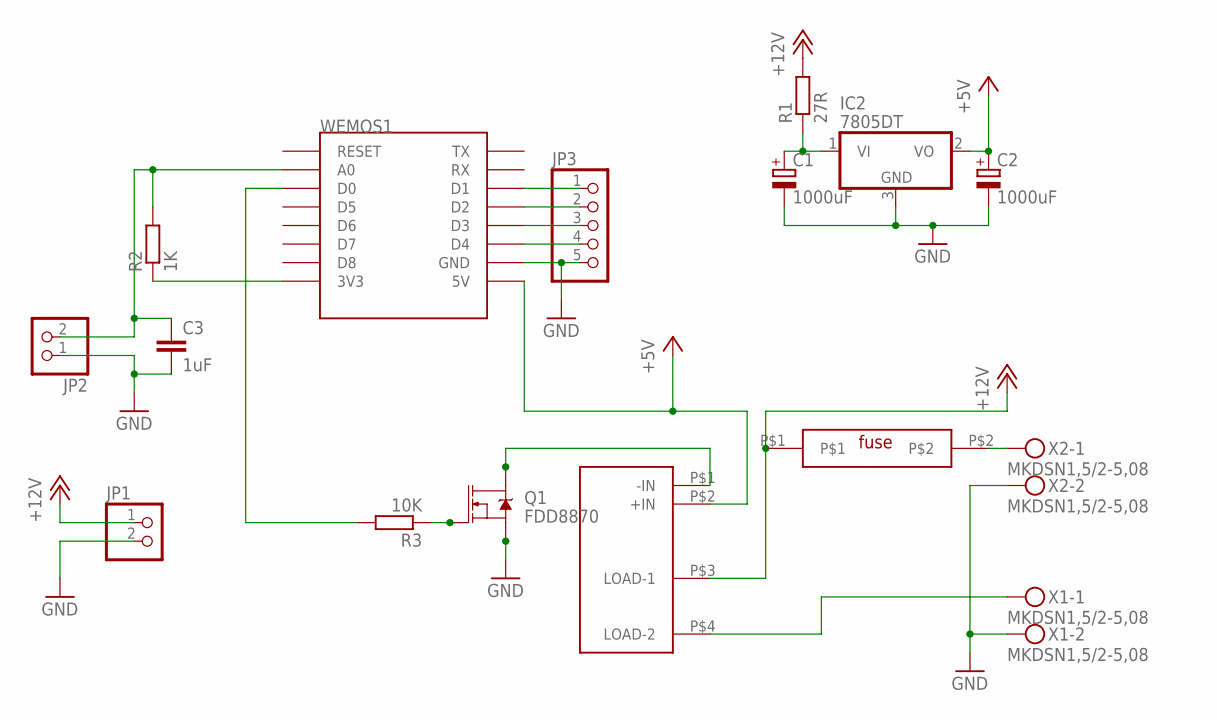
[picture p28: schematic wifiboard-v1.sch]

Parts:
C1, C2: 1000uF; B45181B
C3: 1uF; C0805
IC2: 7805DT; TO252
JP1, JP2: PINHD-1X2; 1X02
JP3: PINHD-1X5; 1X05
Q1: FDD8870; DPAK
R1: 27R; 0207/10
R2: 1K; M0805
R3: 10K; M0805
U$1: OMRON-G6DS; OMRON-G6DS-1A-H
U$2: FUSE
WEMOS1: WEMOS-D1-MINI
X1, X2: MKDSN1,5/2-5,08

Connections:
+5V: C2.+, IC2.2 (VO), U$1.P$2 (+IN), WEMOS1.5V
+12V: JP1.1, R1.2, U$1.P$3 (LOAD-1), U$2.P$1
GND: C1.-, C2.-, C3.2, IC2.3 (GND), JP1.2, JP2.1, JP3.5, Q1.3 (S), WEMOS1.GND, X1.2, X2.2
unnamed: C1.+, IC2.1 (VI), R1.1
unnamed: C3.1, JP2.2, R2.2, WEMOS1.A0
unnamed: R2.1, WEMOS1.3V3
unnamed: Q1.1 (G), R3.1
unnamed: R3.2, WEMOS1.D0
unnamed: Q1.4 (D), U$1.P$1 (-IN)
unnamed: U$1.P$4 (LOAD-2), X1.1
unnamed: JP3.4, WEMOS1.D4
unnamed: U$2.P$2, X2.1
unnamed: JP3.3, WEMOS1.D3
unnamed: JP3.2, WEMOS1.D2
unnamed: JP3.1, WEMOS1.D1

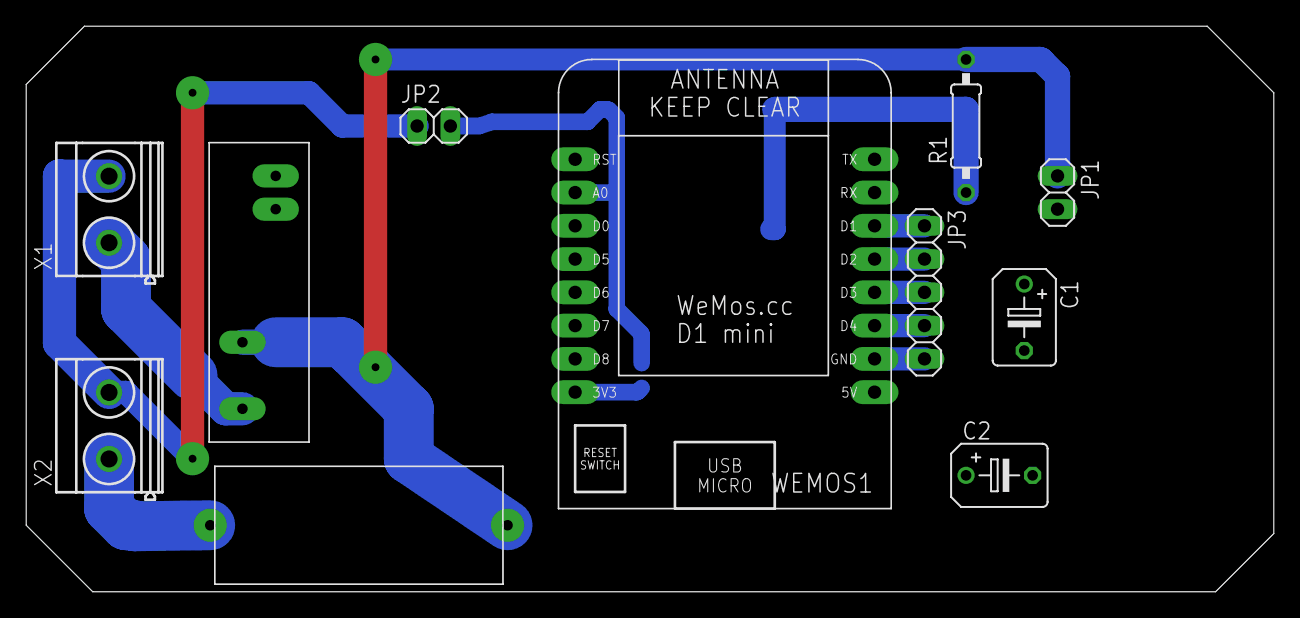
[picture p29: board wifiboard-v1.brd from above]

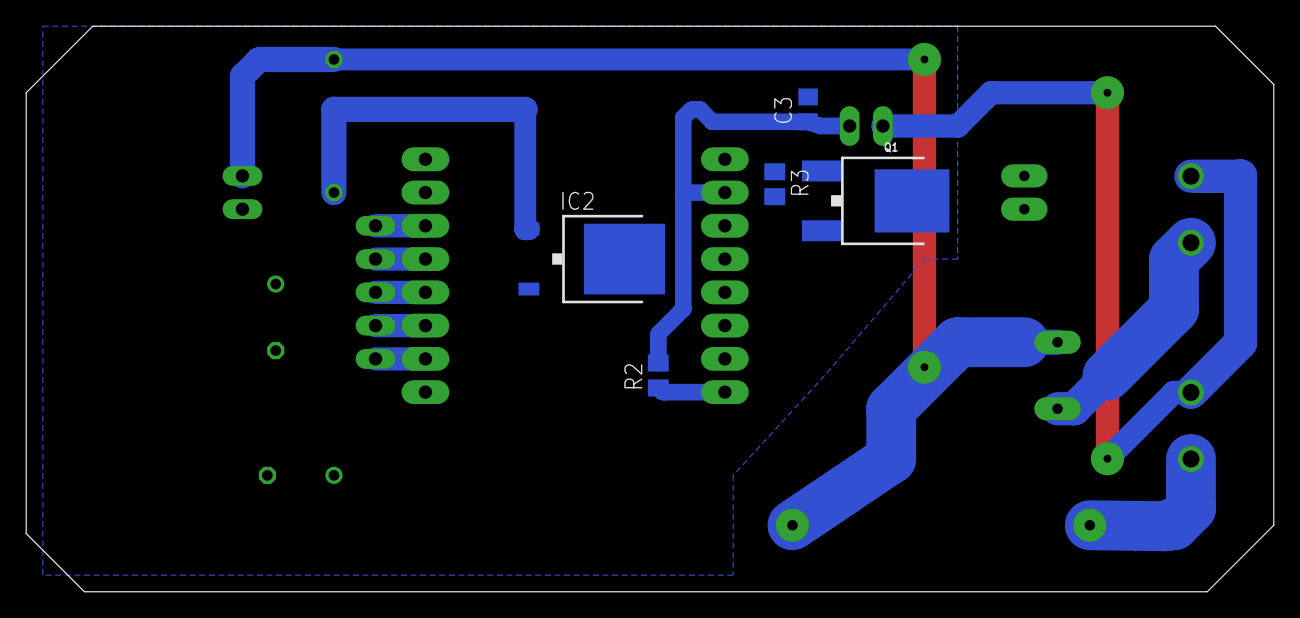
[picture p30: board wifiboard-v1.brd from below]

Board: 2 copper layers, 95.2 x 43.2 mm, 16 parts (5 on the bottom side), 15 nets.

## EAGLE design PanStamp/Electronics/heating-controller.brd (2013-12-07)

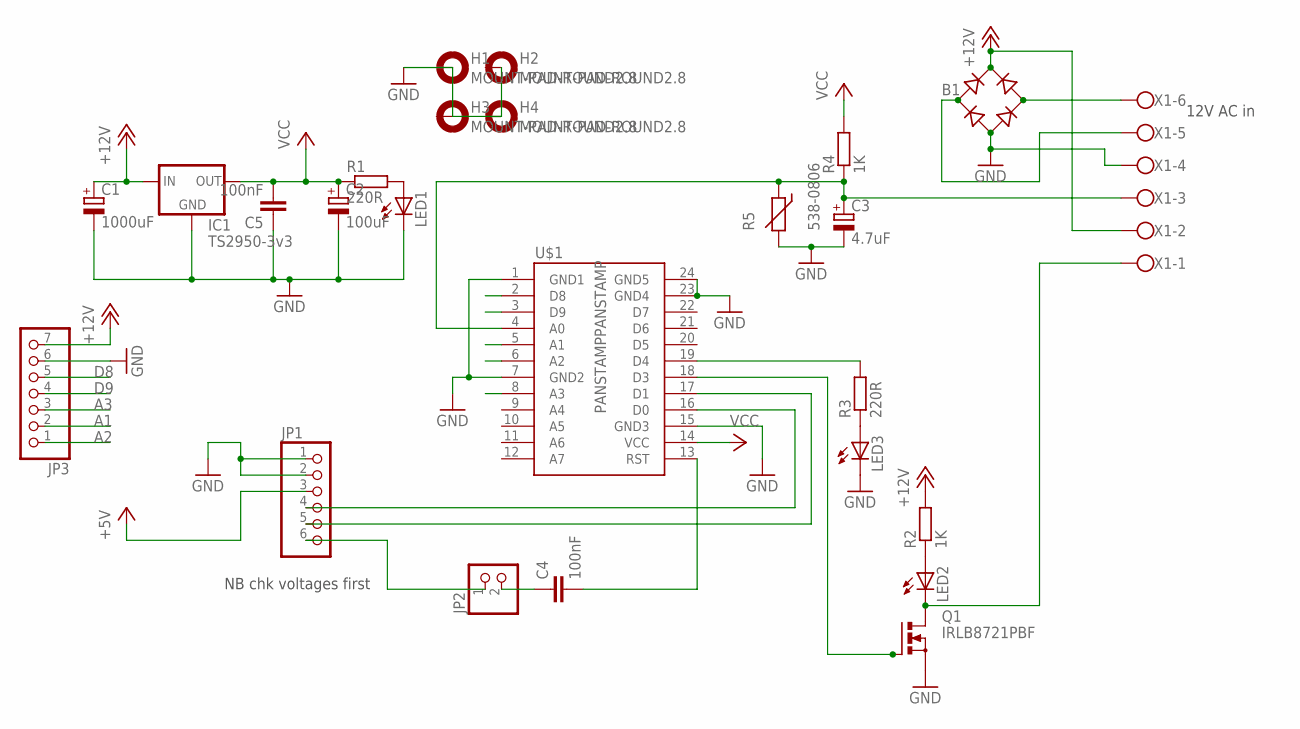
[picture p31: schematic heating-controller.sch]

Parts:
B1: B-DIL
C1: 1000uF; E3,5-10
C2: 100uF; E3,5-10
C3: 4.7uF; E3,5-10
C4, C5: 100nF; C050-024X044
H1, H2, H3, H4: MOUNT-PAD-ROUND2.8; 2,8-PAD
IC1: TS2950-3v3; TO92
JP1: PINHD-1X6; 1X06
JP2: PINHD-1X2; 1X02
JP3: PINHD-1X7; 1X07
LED1, LED2, LED3: LED3MM
Q1: IRLB8721PBF; TO220BV
R1, R3: 220R; 0207/7
R2, R4: 1K; 0207/7
R5: 538-0806; RS-2,5
U$1: PANSTAMPPANSTAMP; DIL24-6
X1: W237-6

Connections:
+5V: JP1.3
+12V: B1.+, C1.+, IC1.3 (IN), JP3.7, R2.2, X1.2
A1: JP3.2, U$1.5 (A1)
A2: JP3.1, U$1.6 (A2)
A3: JP3.3, U$1.8 (A3)
D8: JP3.5, U$1.2 (D8)
D9: JP3.4, U$1.3 (D9)
GND: B1.-, C1.-, C2.-, C3.-, C5.1, IC1.2 (GND), JP1.1, JP1.2, JP3.6, LED1.K (C), LED3.K (C), Q1.S, R5.2, U$1.1 (GND1), U$1.7 (GND2), U$1.15 (GND3), U$1.23 (GND4), U$1.24 (GND5), X1.4
unnamed: C3.+, R4.1, R5.1, U$1.4 (A0), X1.3
unnamed: R3.2, U$1.19 (D4)
unnamed: LED2.K (C), Q1.D, X1.1
unnamed: LED1.A, R1.2
unnamed: LED2.A, R2.1
unnamed: LED3.A, R3.1
unnamed: Q1.G, U$1.18 (D3)
unnamed: C4.1, JP2.2
unnamed: JP1.4, U$1.16 (D0)
unnamed: JP1.5, U$1.17 (D1)
unnamed: B1.AC1, X1.6
unnamed: JP1.6, JP2.1
unnamed: B1.AC2, X1.5
unnamed: C4.2, U$1.13 (RST)
VCC: C2.+, C5.2, IC1.1 (OUT), R1.1, R4.2, U$1.14 (VCC)

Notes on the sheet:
NB chk voltages first
12V AC in

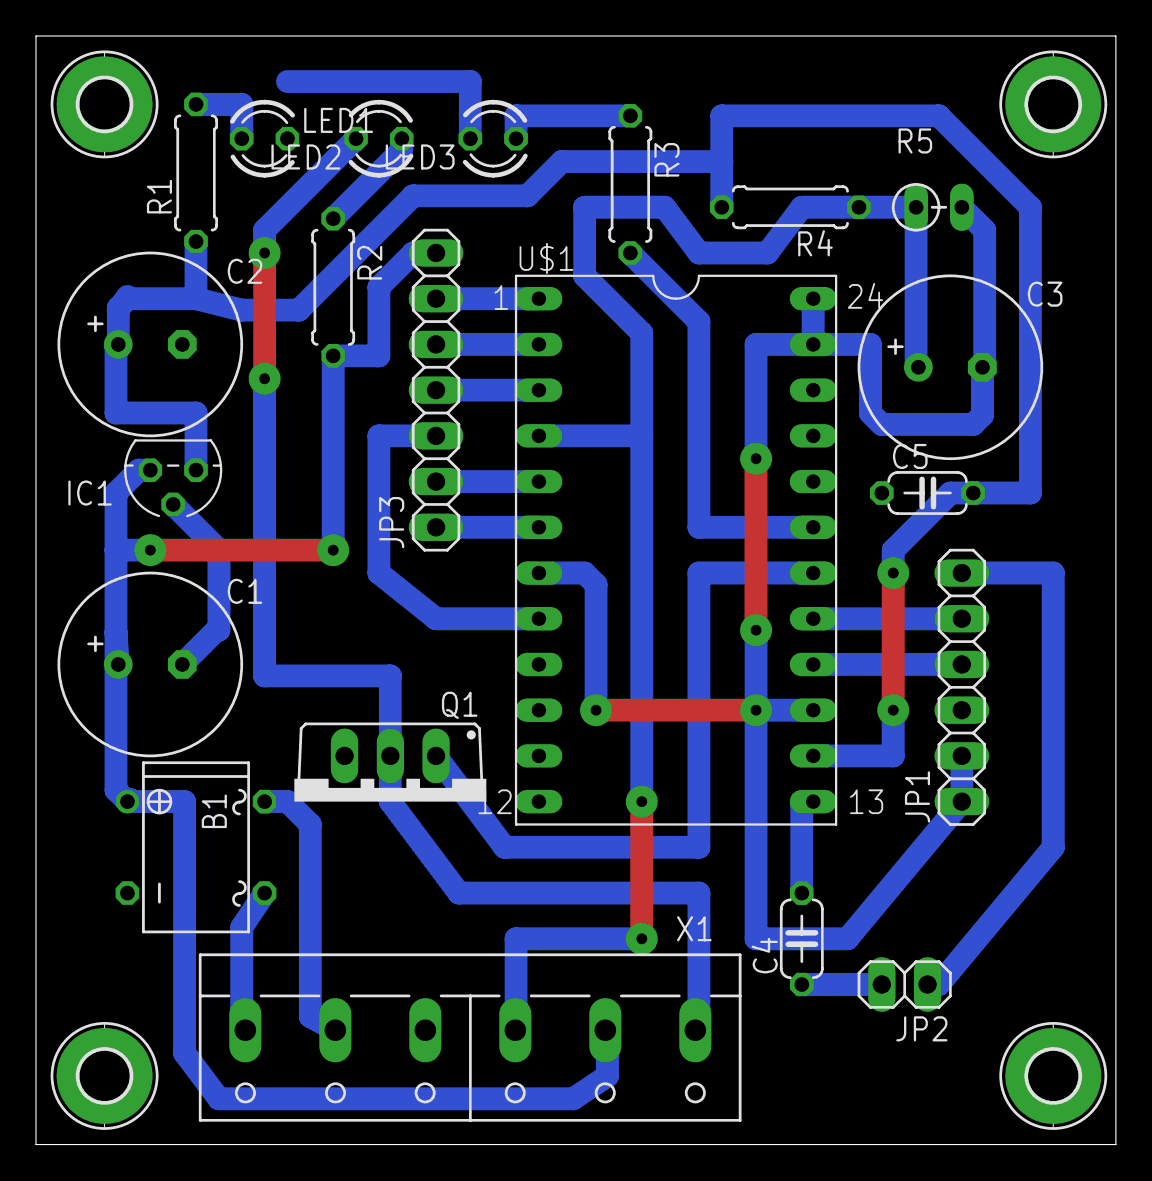
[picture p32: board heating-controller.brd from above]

Board: 2 copper layers, 60.0 x 61.6 mm, 25 parts (0 on the bottom side), 22 nets.

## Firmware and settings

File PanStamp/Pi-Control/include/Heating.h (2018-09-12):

/*
 * Heating.h
 *
 *  Created on: Jan 13, 2014
 *      Author: ensab
 */

#ifndef HEATING_H_
#define HEATING_H_

#define NAME_LENGTH 50

#define LINE_LENGTH 300
#define MIN_INPUT_LENGTH 11
#define DEFAULT_TEMPERATURE_SUMMER 27.0
#define DEFAULT_TEMPERATURE_WINTER 9.0
#define TOP_PAN 100
#define SD '*'
#define OFF_TEMPERATURE 10.0
#define BOOST_TEMPERATURE 27.0

//#define BAUD_RATE BAUD_38400
#define BAUD_RATE BAUD_9600

class Line;
class HeatProfile;
class Wireless;
class Device;
class Heating;

#include <SerialStream.h>
#include <iostream>
#include <fstream>
#include <unistd.h>
#include <cstdlib>
#include <string>
#include <cstring>
#include <stdio.h>
#include <sstream>
#include <math.h>

#include "Line.h"
#include "HeatProfile.h"
#include "Wireless.h"
#include "Device.h"

void ReadQuotedString(std::stringstream& profileFileLine, char* s);
Device* FindDevice(char* name);
char* TimeString(struct tm *timeinfo);
char* TimeString(time_t *rawtime);

extern HeatProfile* heatProfileList;
extern Wireless* wireless;
extern Device* deviceList;
extern char scratchString[];
extern Device* scratchDevices[];
extern int debug;
extern float defaultTemperature;

class Heating
{
public:
	Heating(char* profileFile, char* port, char* tempFile);
	void Run(time_t *rawtime);
	void PrintHeating(std::ostream& os);
	bool Failed() { return error; }

private:
	std::ifstream webProfileFile;
	std::ifstream oldTemperatureLogFile;
	std::ofstream temperatureLogFile;
	bool error;
};




#endif /* HEATING_H_ */

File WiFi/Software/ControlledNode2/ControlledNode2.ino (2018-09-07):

/*
 * Program to run a node on the WiFi Heating Control system.
 * 
 * This makes periodic requests to the server to report its state (on or off,
 * current temperature etc) and to find out what to do next.
 * 
 * The general form of a request is (N.B. "/" caracters should be in the strings):
 * 
 * GET http://currentServer/pageRoot/page/?messageString
 * 
 * where messageString is something like
 * 
 * building=Workshop&location=Office&temperature=20&debugOn=1
 * 
 * Select 
 * 
 *   Board: WeMos D1 R1 
 * 
 * to compile.
 * 
 * Adrian Bwowyer
 * RepRap Ltd
 * http://reprapltd.com
 * 
 * Version 2
 * 5 September 2018
 * 
 * Licence: GPL
 * 
 * 
 */

#include <Arduino.h>

#include <ESP8266WiFi.h>
#include <ESP8266WiFiMulti.h>

#include <ESP8266HTTPClient.h>

//-----------------------------------------------------------------------------------------------------

// User configuration area


/*

The file local_wifi.h included below should contain two lines:

const char* ssid = "-------";      // The name of your WiFi network
const char* password = "--------"; // Your WiFi network's password

*/

#include "local_wifi.h" // Separated to prevent passwords appearing on Github

#define WIFIBOARD-V2
//#define WEMOS1

#ifdef WIFIBOARD-V2
 #define ESP8266_LED_PIN 2           // ESP8266 internal LED; D4 on later PCBs?
 #define USER_LED_PIN D6             // GPIO 12 - Front panel LED
 #define OUTPUT_PIN D3               // GPIO5 This is the switched MOSFET/relay
 #define THERMISTOR_BETA 3528.0      // thermistor: RS 538-0806
 #define THERMISTOR_SERIES_R 10000   // Ohms in series with the thermistor
 #define THERMISTOR_25_R 1000.0      // Thermistor ohms at 25 C = 298.15 K
 #define TOP_VOLTAGE 3.303           // The voltage at the top of the series resistor
 #define MAX_AD_VOLTAGE 1.0          // The voltage that gives full-range (i.e. AD_RANGE - see below) on the A->D converter
 #define T_CORRECTION 1.5            // Final fudge to get it just right/variation in beta from spec
 #define DEBUG_PIN D5                // Ground this pin to turn debugging on
#endif

#ifdef WEMOS1
 #define ESP8266_LED_PIN 2            // D4 on later PCBs?
 #define USER_LED_PIN D6              // GPIO 12 - Front panel LED
 #define OUTPUT_PIN D2                // This is the switched MOSFET/relay                  
 #define THERMISTOR_BETA 3528.0       // thermistor: RS 538-0806
 #define THERMISTOR_SERIES_R 1000     // Ohms in series with the thermistor
 #define THERMISTOR_25_R 1000.0       // Thermistor ohms at 25 C = 298.15 K
 #define TOP_VOLTAGE 3.3              // The voltage at the top of the series resistor
 #define MAX_AD_VOLTAGE TOP_VOLTAGE   // The voltage that gives full-range (i.e. AD_RANGE - see below) on the A->D converter
 #define T_CORRECTION 6               // Final fudge to get it just right/variation in beta from spec 
 #define DEBUG_PIN D5                 // Ground this pin to turn debugging on
#endif

const long debugSampleTime = 15000;   // Milliseconds between server requests when debugging
const long debugRandomTime = 2000;    // +/- Milliseconds (must be < sampleTime) used to randomise requests to reduce clashes

const long sampleTime = 60000;        // Milliseconds between server requests
const long randomTime = 5000;         // +/- Milliseconds (must be < sampleTime) used to randomise requests to reduce clashes

const long rebootTime = 3600000;      // Milliseconds between resets.

#define BAUD 9600     // Serial comms speed

const int version = 2;
const String myName = "ElectronicsLab";             // What room/device am I controlling?
const String building = "Workshop";               // Which building is the device in?
const String pageRoot = "/WiFiHeating/";          // Where the .php script is on the server
const String page = "controllednode.php";         // The script we need
String server = "adrianbowyer.com";               // Server IP address/URL
String backupServer = "192.168.1.171";            // Backup server IP address/URL
String currentServer = server;                    // The one in use

//-----------------------------------------------------------------------------------------------------------


// Bits of HTML we need to know (both cases of these are tried in atempting matches)

const String bodyStart = "<body>";        // The instructions are in the body of the loaded page
const String bodyEnd = "</body>";
const String htmlBreak = "<br>";

// The thermistor for measuring temperature

#define ABS_ZERO -273.15           // Celsius
#define TEMP_SENSE_PIN 0           // Analogue pin number
#define AD_RANGE 1023.0            // The A->D converter that measures temperatures gives an int this big as its max value

// This is turned off and on when running by freeing/grounding DEBUG_PIN

bool debug = true;

// LED control and blinking 

#define OFF 1 // N.B. ESP8266 LED is inverted
#define ON 0
#define DOT 2
const int dotOn = 100;
const int dotOff = 500;
#define DASH 3
const int dashOn = 500;
const int dashOff = 100;
#define FLASH 4
const int flashOn = 100;
const int flashOff = 100;
long nextBlink;
byte blinkPattern;
byte ledState;

// Text and messages

String message = "";

// Timing and resets

long nextTime;
long nextReset;
long onSecondCount;
long offSecondCount;
long seconds;

bool loadIsOn;

ESP8266WiFiMulti WiFiMulti;

void setup() 
{
   // I/O pins...
  
  pinMode(ESP8266_LED_PIN, OUTPUT);
  pinMode(USER_LED_PIN, OUTPUT);
  digitalWrite(ESP8266_LED_PIN, OFF);
  digitalWrite(USER_LED_PIN, !OFF);
  ledState = OFF;
  pinMode(OUTPUT_PIN, OUTPUT);
  digitalWrite(OUTPUT_PIN, 0);
  pinMode(TEMP_SENSE_PIN, INPUT);
  pinMode(DEBUG_PIN, INPUT_PULLUP);
  debug = !digitalRead(DEBUG_PIN);

  Serial.begin(BAUD);

  while(!Serial);

  if(debug)
  {
    Serial.println();
    Serial.println();
    Serial.print("I am: ");
    Serial.print(myName);
    Serial.print(" in ");
    Serial.println(building);    
    Serial.print("Connecting to WiFi: ");
    Serial.print(ssid);
  }

  // Needed for WiFi stability
  
  delay(4000);

  WiFi.mode(WIFI_STA);
  WiFiMulti.addAP(ssid, password);

  // Set up timings and LED behaviour
  
  randomSeed(analogRead(TEMP_SENSE_PIN));
  blinkPattern = OFF;
  onSecondCount = -1;
  offSecondCount = -1;
  loadIsOn = false;
  nextTime = (long)millis();
  nextBlink = nextTime;
  seconds = nextTime;
  nextReset = nextTime + rebootTime;
}


// Amuse the user with blinking lights

void Leds(int onOff)
{
  digitalWrite(ESP8266_LED_PIN, onOff);
  digitalWrite(USER_LED_PIN, !onOff);
  ledState = onOff;
}

void Blink()
{
  long now = millis();
  
  if(blinkPattern == OFF || blinkPattern == ON)
  {
    Leds(blinkPattern);
    nextBlink = now;
    return; 
  }
  
  if(now - nextBlink < 0)
    return;

  switch(blinkPattern)
  {
    case DOT:
      if(ledState == ON)
      {
        Leds(OFF);
        nextBlink = now + dotOff;
      } else
      {
        Leds(ON);
        nextBlink = now + dotOn;
      }
      break;
      
    case FLASH:
      if(ledState == ON)
      {
        Leds(OFF);
        nextBlink = now + flashOff;
      } else
      {
        Leds(ON);
        nextBlink = now + flashOn;
      }
      break;
      
    case DASH:
    default:
      if(ledState == ON)
      {
        Leds(OFF);
        nextBlink = now + dashOff;
      } else
      {
        Leds(ON);
        nextBlink = now + dashOn;
      }    
  }
}


// Return the celsius temperature as a text string

String Temperature()
{
  double r = (double)analogRead(TEMP_SENSE_PIN);
  //Serial.println(r);
  r = T_CORRECTION + ABS_ZERO + THERMISTOR_BETA/log( (r*THERMISTOR_SERIES_R/(AD_RANGE*TOP_VOLTAGE/MAX_AD_VOLTAGE - r))/
      ( THERMISTOR_25_R*exp(-THERMISTOR_BETA/(25.0 - ABS_ZERO)) ) );
  return String(r, 1);
}


// Assemble the HTTP request in the message String

void ComposeQuery()
{
  message = "http://";
  message.concat(currentServer);
  message.concat(pageRoot);
  message.concat(page);
  message.concat("?building=");
  message.concat(building);
  message.concat("&location=");
  message.concat(myName);
  message.concat("&temperature=");
  message.concat(Temperature());
  if(debug)
  {
    message.concat("&debugOn=1");
  }
}


// Decide the time delay before the next server request.  This is usually quick (~15s) for debugging
// (so you can see what's going on), or slow (~60s) for normal operation.

long NextTime()
{
  long f;
  if(debug)
    f = debugSampleTime + random(2*debugRandomTime) - debugRandomTime;
  else
    f = sampleTime + random(2*randomTime) - randomTime;
    
  if(debug)
  {
    Serial.print("Next server request will be in ");
    Serial.print(f);
    Serial.println(" milliseconds.");
  }
  return (long)millis() + f;
}


// Print the HTML body returned from the server on Serial output replacing
// HTML controls with readable stuff.

void PrintWebPageReturned(int bod)
{
  int end = message.indexOf(bodyEnd);
  String temp;
  
  if(end < 0)
  {
    temp = bodyEnd;
    temp.toUpperCase();
    end = message.indexOf(temp);
    if(end < 0)
    {
      blinkPattern=DASH;
      if(debug)
      {
        Serial.print(bodyEnd);
        Serial.print(" not found in ");
        Serial.println(message);
      }
    }
  }

  // Pull out the body of the message (note this overwrites message)
  
  if(end < 0)
    message = message.substring(bod);
  else
    message = message.substring(bod, end);

  // Replace <br> with \n
  
  temp = htmlBreak;
  if(message.indexOf(temp) < 0)
    temp.toUpperCase();
  message.replace(temp, "\n");

  Serial.println("\n--------");
  Serial.println(message);
  Serial.println("--------\n");  
}

// This gets called once a second and
// handles delayed switching.

void TimedOnOrOff()
{
  if(onSecondCount > 0)
    onSecondCount--;

  if(onSecondCount == 0)
  {
    if(debug)
       Serial.println("Switching on.");
    blinkPattern = ON;
    digitalWrite(OUTPUT_PIN, 1);
    loadIsOn = true;
    onSecondCount = -1;
  }

  if(offSecondCount > 0)
    offSecondCount--;

  if(offSecondCount == 0)
  {
    if(debug)
       Serial.println("Switching off.");
    blinkPattern = OFF;
    digitalWrite(OUTPUT_PIN, 0);
    loadIsOn = false;
    offSecondCount = -1;
  }    
}


// Turn the load (central heating valve, or whatever) on or off
// This doesn't actually change the state of the load, it just
// sets a seconds count (which can be 0) for when that change is to be made in the future.

void SwitchOnOrOff(bool on, long tim)
{
  if(debug)
    Serial.print("Switching ");
    
  if(on)
  {
   if(onSecondCount >= 0)
   {
    if(debug)
      Serial.println("**ON timer running");
    return;
   }
   onSecondCount = tim;
   if(debug)
   {
    Serial.print("ON in ");
    Serial.print(onSecondCount);
    Serial.println(" seconds.");
   }
   return;    
  }

  if(offSecondCount >= 0)
  {
    if(debug)
      Serial.println("**OFF timer running");
    return;
  }
  offSecondCount = tim;
  if(debug)
  {
    Serial.print("OFF in ");
    Serial.print(offSecondCount);
    Serial.println(" seconds.");
  } 
}


// Go through the body of the HTML returned from the server and decide what
// action it's instructing us to take.

void ParseMessage()
{
  int bod = message.indexOf(bodyStart);
  
  if(bod < 0)
  {
    String temp = bodyStart;
    temp.toUpperCase();
    bod = message.indexOf(temp);
    if(bod < 0)
    {
      blinkPattern=DASH;
      if(debug)
      {
        Serial.print(bodyStart);
        Serial.print(" not found in ");
        Serial.println(message);
      }
      return;
    }
  }

  bod += bodyStart.length();
  int toDo = message.indexOf("ON", bod);

  if(toDo < 0)
  {
    toDo = message.indexOf("OFF", bod);
    if(toDo < 0)
    {
      blinkPattern=DASH;
      if(debug)
      {
        Serial.print("Neither ON nor OFF found in ");
        Serial.println(message);
      }
      return;     
    }
    SwitchOnOrOff(false, message.substring(toDo+4).toInt());
  } else
  {
    SwitchOnOrOff(true, message.substring(toDo+3).toInt());
  }

  if(debug)
    PrintWebPageReturned(bod);
}

// This handles counting seconds and doing things when a second ticks

void SecondCounter()
{
  long t = millis();
  if(t - seconds > 0)
  {
    seconds = t + 1000;
    TimedOnOrOff();
  }
}


// What it says...

void loop() 
{
  // Check for watchdog reset time
  
    if((long)millis() - nextReset > 0)
    {
      if(debug)
        Serial.println("\n\n*** Watchdog reset.\n");
      delay(2000); // Allow the serial output buffer to flush
      ESP.restart();
    }

  // If the HTTP request will be in 1 second, flash the LEDs...
  
  if((1000 + (long)millis()) - nextTime > 0)
    blinkPattern=FLASH;

  // Time for another HTTP request?
  
  if((long)millis() - nextTime > 0)
  {
    if(loadIsOn)
      blinkPattern=ON;
    else
      blinkPattern=OFF;
      
    // wait for WiFi connection
    if ((WiFiMulti.run() == WL_CONNECTED)) 
    {
      if(debug)
        Serial.println();
  
      HTTPClient http;
  
      ComposeQuery();
  
      if(debug)
      {
        Serial.print("\nSending: ");
        Serial.println(message);
      }
   
      http.begin(message);
      
      // start connection and send HTTP header
      
      int httpCode = http.GET();
  
      // httpCode will be negative on error
      
      if (httpCode > 0) 
      {
        // HTTP header has been send and Server response header has been handled
        
        if(debug)
          Serial.printf("HTTP GET returned code: %d\n", httpCode);
  
        // file found at server
        
        if (httpCode == HTTP_CODE_OK) 
        {
          message = http.getString();
          ParseMessage();
        } else
        {
          blinkPattern = DASH;
          if(debug)
            Serial.println("\nReturned code not HTTP_CODE_OK");
        }
      } else 
      {
        blinkPattern = DASH;
        if(debug)
          Serial.printf("\nHTTP GET failed, error: %s\n", http.errorToString(httpCode).c_str());
      }
  
      http.end();
      
    } else
    {
      if(debug)
        Serial.println("\nNot WL_CONNECTED.");    
    }
  
    nextTime = NextTime();
  }

  debug = !digitalRead(DEBUG_PIN);

  // Entertain the user
  
  Blink();

  // Timing by seconds
  
  SecondCounter();

}

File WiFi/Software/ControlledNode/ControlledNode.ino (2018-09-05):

/*
 * Program to run a node on the WiFi Heating Control system.
 * 
 * This makes periodic requests to the server to report its state (on or off,
 * current temperature etc) and to find out what to do next.
 * 
 * The general form of a request is (N.B. "/" caracters should be in the strings):
 * 
 * GET http://currentServer/pageRoot/page/?messageString
 * 
 * where messageString is something like
 * 
 * location=Office&temperature=20&debugOn=1
 * 
 * Select 
 * 
 *   Board: WeMos D1 R1 
 * 
 * to compile.
 * 
 * Adrian Bwowyer
 * RepRap Ltd
 * http://reprapltd.com
 * 
 * 29 December 2017
 * 
 * Licence: GPL
 * 
 * 
 */

#include <ESP8266WiFi.h>

#include <ESP8266WiFiMulti.h>
#include <ESP8266HTTPClient.h>
ESP8266WiFiMulti WiFiMulti;

//-----------------------------------------------------------------------------------------------------

// User configuration area


/*

The file local_wifi.h included below should contain two lines:

const char* ssid = "-------";      // The name of your WiFi network
const char* password = "--------"; // Your WiFi network's password

*/

#include "local_wifi.h" // Separated to prevent passwords appearing on Github

#define WIFIBOARD-V2
//#define WEMOS1

#ifdef WIFIBOARD-V2
 #define ESP8266_LED_PIN 2                    // D4 on later PCBs?
 #define OUTPUT_PIN D3                  //GPIO5
 #define THERMISTOR_BETA 3528.0      // thermistor: RS 538-0806
 #define THERMISTOR_SERIES_R 10000   // Ohms in series with the thermistors
 #define THERMISTOR_25_R 1000.0      // Thermistor ohms at 25 C = 298.15 K
 #define TOP_VOLTAGE 3.303           // The voltage at the top of the series resistor
 #define MAX_AD_VOLTAGE 1.0          // The voltage that gives full-range (i.e. AD_RANGE) on the A->D converter
 #define T_CORRECTION 1.5            // Final fudge to get it just right/variation in beta from spec
 #define DEBUG_PIN D5
#endif

#ifdef WEMOS1
 #define ESP8266_LED_PIN 2                    // D4 on later PCBs?
 #define OUTPUT_PIN D2                  
 #define THERMISTOR_BETA 3528.0      // thermistor: RS 538-0806
 #define THERMISTOR_SERIES_R 1000   // Ohms in series with the thermistors
 #define THERMISTOR_25_R 1000.0      // Thermistor ohms at 25 C = 298.15 K
 #define TOP_VOLTAGE 3.3           // The voltage at the top of the series resistor
 #define MAX_AD_VOLTAGE TOP_VOLTAGE          // The voltage that gives full-range (i.e. AD_RANGE) on the A->D converter
 #define T_CORRECTION 6            // Final fudge to get it just right/variation in beta from spec 
 #define DEBUG_PIN D5                 // Ground this pin to turn debugging on
#endif

const long debugSampleTime = 15000;           // Milliseconds between server requests
const long debugRandomTime = 2000;            // +/- Milliseconds (must be < sampleTime) used to randomise requests to reduce clashes

const long sampleTime = 60000;           // Milliseconds between server requests
const long randomTime = 5000;            // +/- Milliseconds (must be < sampleTime) used to randomise requests to reduce clashes

const long rebootTime = 3600000;           // Milliseconds between resets.

//-----------------------------------------------------------------------------------------------------------

//WiFiClient client;

// Typical HTML response with debugging is about 350 bytes.

#define MAXC 1000     // Maximum bytes in a message string (need a bit of space for debugging info).
#define TEMPC 10      // Maximum bytes in a temperature string

#define BAUD 9600     // Serial comms speed

const char* myName = "Office";   // What am I controlling?
const char* pageRoot = "/WiFiHeating/Workshop/"; // Where the .php script is on the server
const char* page = "controllednode.php";    // The script we need
char* server = "adrianbowyer.com";    // Server IP address/URL
char* backupServer = "192.168.1.171"; // Server IP address/URL
char* currentServer;                        // The one in use

// Bits of HTML we need to know (not case sensitive)

const char* bodyStart = "<BODY>";        // The instructions are in the body of the loaded page
const char* bodyEnd = "</BODY>";
const char* htmlBreak = "<BR>";

#define ABS_ZERO -273.15           // Celsius
#define TEMP_SENSE_PIN 0           // Analogue pin number
#define AD_RANGE 1023.0            // The A->D converter that measures temperatures gives an int this big as its max value

bool debug = true;

// LED control and blinking 

#define OFF 1 // NB LED is inverted
#define ON 0
#define DOT 2
const int dotOn = 100;
const int dotOff = 500;
#define DASH 3
const int dashOn = 500;
const int dashOff = 100;
long nextBlink;
byte blinkPattern;
byte ledState;

// Text and messages

char messageString[MAXC];
char tempString[TEMPC];
int messageCount;
int tagCount;
bool inMessage;
long nextTime;

long nextReset;

void setup() 
{
  // I/O pins...
  
  pinMode(ESP8266_LED_PIN, OUTPUT);
  digitalWrite(ESP8266_LED_PIN, OFF);
  ledState = OFF;
  pinMode(OUTPUT_PIN, OUTPUT);
  digitalWrite(OUTPUT_PIN, 0);
  pinMode(TEMP_SENSE_PIN, INPUT);
  pinMode(DEBUG_PIN, INPUT_PULLUP);
  debug = !digitalRead(DEBUG_PIN);
  
  // Open serial communications and wait for the port to open
  
  Serial.begin(9600);
  while (!Serial) 
  {
    ; // wait for serial port to connect.
  }
  
  // Identify then connect to WiFi network
  
  if(debug)
  {
    Serial.println();
    Serial.println();
    Serial.print("I am: ");
    Serial.println(myName);
    Serial.print("Connecting to WiFi: ");
    Serial.print(ssid);
  }

  WiFi.mode(WIFI_STA);
  WiFiMulti.addAP(ssid, password);
/*  
  while (WiFiMulti.run() != WL_CONNECTED) 
  {
    delay(500);
    if(debug)
      Serial.print(".");
  }
  if(debug)
  {
    Serial.print("\nConnected to ");
    Serial.println(ssid);
  }
*/
  // Set up timings and LED behaviour
  
  randomSeed(analogRead(TEMP_SENSE_PIN));
  nextTime = (long)millis();
  nextBlink = nextTime;
  nextReset = nextTime + rebootTime;
  blinkPattern = OFF;
}


// Handles LED blink patterns

void Blink()
{
  long now = millis();
  
  if(blinkPattern == OFF || blinkPattern == ON)
  {
    digitalWrite(ESP8266_LED_PIN, blinkPattern);
    ledState = blinkPattern;
    nextBlink = now;
    return; 
  }
  
  if(now - nextBlink < 0)
    return;
  
  if(blinkPattern == DOT)
  {
    if(ledState == ON)
    {
      digitalWrite(ESP8266_LED_PIN, OFF);
      ledState = OFF;
      nextBlink = now + dotOff;
    } else
    {
      digitalWrite(ESP8266_LED_PIN, ON);
      ledState = ON;
      nextBlink = now + dotOn;
    }
    return;
  }

  // The default (DASH) is the error signal
  
  if(ledState == ON)
  {
    digitalWrite(ESP8266_LED_PIN, OFF);
    ledState = OFF;
    nextBlink = now + dashOff;
  } else
  {
    digitalWrite(ESP8266_LED_PIN, ON);
    ledState = ON;
    nextBlink = now + dashOn;
  }
}

// Return the celsius temperature as a text string
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

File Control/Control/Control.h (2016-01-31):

// Only modify this file to include
// - function definitions (prototypes)
// - include files
// - extern variable definitions
// In the appropriate section

#ifndef Control_H_
#define Control_H_
#include "Arduino.h"
#include <Time.h>
#include <avr/wdt.h>

#include "Debug.h"
#include "Communicator.h"
#include "CommandBuffer.h"
#include "Switch.h"
#include "Light.h"

#define MY_ADDRESS 100
#define HOST 31
#define PLACE "Test"
#define NAME "WiControl"
#define DATE "2016-01-31"
#define VERSION "0.15"

#define BAUD_RATE 38400

// Uncomment this to enable LED control
//#define USE_LEDS

#define DATA_LENGTH 60

// The LED is wired to the Arduino Output 4 (physical panStamp pin 19)
#define FLASHOUTPUT 4

#ifdef USE_LEDS
// RGB PWM outputs
#define RED_PWM 6
#define GREEN_PWM 5
#define BLUE_PWM 9
#endif

#define RESET_SECONDS 90

#define ABS_ZERO -273.15  // Celsius
#define TEMP_SENSE_PIN 0   // Analogue pin number

// Outputs for controlling various things.  D_OUTPUT_1 is the MOSFET
// D_OUTPUT_2 is the first output on the 7 pin header, which from the top goes:
// 12v, Gnd, D8, D9, A3 = D17, A1 = D15, A2 = D16
// D_OUTPUT_3 is not available if LEDS are being controlled

#ifndef USE_LEDS
 #define SWITCHES 7
 #define OUT_PINS {3, 8, 9, 17, 15, 16, FLASHOUTPUT}
 #define FLASH 6
 #define RED FLASH
 #define GREEN FLASH
 #define BLUE FLASH
 //#define WATCHDOG
#else
 #define SWITCHES 9
 #define OUT_PINS {3, 8, 17, 15, 16, RED_PWM, GREEN_PWM, BLUE_PWM, FLASHOUTPUT};
 #define FLASH 8
 #define RED 5
 #define GREEN 6
 #define BLUE 7
#endif

#define THERMISTOR_BETA 3528.0 // thermistor: RS 538-0806
#define THERMISTOR_SERIES_R 1000 // Ohms in series with the thermistors
#define THERMISTOR_25_R 1000.0 // Thermistor ohms at 25 C = 298.15 K
#define AD_RANGE 1023.0 // The A->D converter that measures temperatures gives an int this big as its max value


void IncommingInterrupt();
void blink();

extern Switch* switches[SWITCHES];
extern Message* message;

#ifdef __cplusplus
extern "C" {
#endif
void loop();
void setup();
#ifdef __cplusplus
} // extern "C"
#endif

#endif /* Control_H_ */

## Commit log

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2013-11-06 Bug: received message never acted on...
    [Command.cpp]
2013-11-15 Thermistor parameters corrected.
2013-11-17 Sketch of controller PCB started in Eagle.
    [heating-controller.brd, heating-controller.sch]
2013-11-17 First version of PCB complete.
    [heating-controller.brd, heating-controller.sch]
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2013-12-07 Smaller 3v3 reg used, that can also stand 20V.
    [heating-controller.brd, heating-controller.sch]
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2014-01-07 BoM spreadsheeet added.
    [case.scad, heating-controller-bom.ods, heating-controller.csv]
2014-01-07 Case design added.
    [case.g, case.scad, case.stl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]
2014-01-30 Watchdog reset added at 30 secs. Timer is reset if a radio message arrives.
    [Control.cpp, Control.h]
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2014-06-14 Added code to invert temperature behaviour to allow the control of cooling devices. Added code to allow the sensor Panstamp number to be different from the switch Panstamp number. Temperature profile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
2014-07-27 Case design improved and made partly parametric.
    [case.scad, long-case.stl, long-lid.stl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]
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2014-08-19 RGB LED lighting control added.
    [BoM.ods]
2014-08-25 Heating control program now allows multiple devices per room and temperature.
    [parametric-case.scad, r-pi-case.stl, r-pi-lid.stl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]
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2014-09-26 Heatprofile bug squashed (deviceCount too big).
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2014-10-12 Correct printf format now used for sending unsigned long time...
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2015-09-20 Host now reads the old temperature profile and uses those temps if wireless to a device fails.
2016-01-17 Bug in Switch class fixed.
2016-07-28 Fixed temperature rounding and transmission as 10* int.
    [PanstampControl.ino]
2016-07-28 Fixed (I think) watchdog.
    [Control.h, Debug.ino, PanstampControl.ino]
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2017-06-05 WeMos design added. Not final (need to replace 78L05 with 7805 to get enough current).
    [wifiboard.brd, wifiboard.sch]
2017-11-14 Working on the WiFi/ESP-8266 version...
    [wifiboard.brd, wifiboard.sch]
2017-12-04 Tidied up wifi files. Added WiFi FreeCAD case.
    [cable-clamp.stl, case.stl, lid.stl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]
2017-12-07 Improved PCB design and casing.
    [base.stl, cable-clamp.stl, case.stl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]
2018-02-15 Remote server working. Backup server added to Arduino code (doesn't yet work...)
    [ControlledNode.ino]
2018-03-15 heating.php improved to check that times monotonically increase throughout the day.
    Various bits of experimental WiFi electronics added.
    [esp-8266-test.brd, esp-8266-test.sch, wifiboard-v1.brd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]
2018-03-16 More correctness checking in heating.php
2018-04-12 Simple web monitoring added to the thermostat program.
    [thermistor-model.ods, wifiboard-v2-parts.csv, wifiboard-v2.brd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]
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2018-05-01 controllednode.php fixed to deal with timezone (maybe summer time too?)
    [thermistor-model.ods]
2018-05-03 Improving the box design. Also fixed daylight saving in controllednode.php
    [lid.stl, pcb-spring-1-2-off.stl, pcb-spring-2.stl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]
2018-07-17 Gerbers for WiFi PCB done.
    [pcb-spring-1-2-off.stl, pcb-spring-2.stl, wifi-case.fcstd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]
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2018-09-04 Test changes; none significant.
    [wifiboard-v2-etch.csv, wifiboard-v2-etch.ods]
2018-09-06 Parts spreadsheet set up. PHP changed to make summertime work.
    [lid.stl, wifi-case.fcstd, wifiboard-v2-etch.ods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]
2018-09-07 Improved case design.
    [led-cover.stl, lid.stl, pcb-spring-1-2-off.stl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]
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2018-09-12 File tidying.
    [BoM.ods, base.stl, cable-clamp.stl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]
2018-09-12 Now with the right names...
    [base.stl, cable-clamp.stl, esp-8266-test.brd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]
2018-09-12 Increasing the number of mains adapters that can be incorporated.
    [base.stl, wifi-case-bumpy.fcstd, wifi-case-round.fcstd]
2018-09-18 New power-supply case added. Tidied file structure. More comments in software.
    [base.stl, cable-clamp.stl, led-cover.stl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]
2018-09-25 Set temp offset to 0. Added complete parts list.
    [parts-list.ods, wifiboard-v2-etch.ods, ws-offsets.ods]
2018-11-07 Firmware now reports internal status, and connecting to WiFi.
    [cable-clampx4.g, led-coverx6.g, parts-list.ods]
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2018-11-29 WIP: Adding a class to record and recover strings from flash memory so that the device can be configured on the fly and remember that when it's powered off then on again.
    [Lid 0.1.stl, wifi-case-bumpy.fcstd]
2018-11-29 Sm. bug spotted and fixed.
    [HomeControlFirmware.ino]
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2019-02-26 New branch.
    Started work on Sally's idea of having each client just identified by a number,
    along with a table on the server that matches numbers to locations.
    New client ESP8266 code compiles...
    [cable-clampx4.g, case.g, led-coverx6.g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]
2019-03-04 Data logging added to the new system.
    [log.csv, log.ods]
2019-03-09 Improved lid design with connector.
    [lid-with-connector.stl, log.ods, log2.csv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]
2019-07-01 Small bug in scontrollednode.php fixed.
    [Temp Sensor Wall Mount.fcstd, TempSensorWallMount.g, TempSensorWallMount.stl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]
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2019-09-24 Sorted out update of globals.php
    [TempSensorWallMount.g, TempSensorWallMount.stl, TempSensorWallMountv0.2.g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]
2019-09-25 Fixed small bug in the .php script; updated URLs for home system.
    [HomeControlFirmware.ino]
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2019-10-18 Fixing (ish) problem with multiple loads. Can't seem to have more than 3, though there's 50K of heap. ???
    [temp-wall-mount.stl]
2019-10-26 Retained crimp plug for valve connection added to design.
    [plug.g, plug.stl, plugx9.g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]
2019-11-14 Fixing transparency, but there seems to be a bug in the screw corner retainers...
    [wifi-case-bumpy.fcstd]
2019-11-14 Fixed fault in walls design. Salvaged from previous commit.
    [wifi-case-bumpy.fcstd]
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2021-04-27 Sally's WIP on new PCB design.
    [SB - wifiboard-v2.kicad_pcb, wifiboard-v2.kicad_pcb, wifiboard-v2.sch]
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2021-06-18 Now saves configuration in EEPROM (if it works...)
    [Divider002.stl, Wifi Patress-Chamfer006.stl, Wifi Patress-Cut014.stl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]
2022-01-11 Added hysterisis to the system's ON/OFF with temperature.
    [Wifi Patress-Lid.stl, Wifi Patress.FCStd]
2022-01-28 Trying to start V4 PCB. Not working yet.
    [back.g, drill.g, outline.g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]
2022-01-31 Redoing V4 electronics to make it fully KiCAD.
    [wifiboard-v4.kicad_pcb, wifiboard-v4.sch]
2022-02-01 V4 schematic complete (?)...
    [wifiboard-v4.sch]
2022-02-02 Components positioned on PCB.
    [wifiboard-v4.sch]
2022-02-03 SB & AB PCB layout
    [wifiboard-v4.kicad_pcb, wifiboard-v4.sch]
2022-02-09 PCB sent for trial production.
    [back.g, drill.g, outline.g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]
2022-02-14 Double patress box front plate design first complete design.
    [double-patress-holder-front-plate.stl, double-patress-holder.FCStd, double-patress-plate.FCStd]
2022-02-15 Improved patress front plate design.
    [double-patress-holder-front-plate.stl, double-patress-holder.FCStd]
2022-02-21 This time with the right size for the PCB...
    [double-patress-holder-front-plate.stl, double-patress-holder.FCStd]
2022-05-20 Keeping things up to date.
    [bom.ods, double-patress-holder-front-plate-no-chamfer.stl, double-patress-holder-front-plate.stl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]
2022-07-06 PCB modified to accommodate relay as well as opto-SCR. GERBERS need to be updated.
    [wifiboard-v4.kicad_pcb]
2024-05-03 Added stuff on hacking existing smart switches, specifically SWA1.
    [double-patress-plate-blank.stl]

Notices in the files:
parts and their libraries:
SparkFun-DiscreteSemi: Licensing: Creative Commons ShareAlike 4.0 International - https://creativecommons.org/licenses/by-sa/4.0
